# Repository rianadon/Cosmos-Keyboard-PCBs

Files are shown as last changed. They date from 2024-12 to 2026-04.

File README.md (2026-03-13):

# Cosmos Keyboard PCBs

This repository contains the sources and specs for the PCBs I've made for my pet project, [Cosmos Keyboard Generator](https://ryanis.cool/cosmos).

## Plum Twist

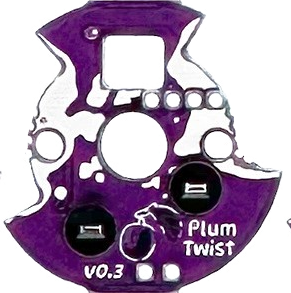
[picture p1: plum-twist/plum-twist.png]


A single-key PCB, with hotswap and RGB support that locks into place. [[Main Website](https://ryanis.cool/cosmos/plum-twist/)] [[Buy](https://cosmos-store.ryanis.cool/products/plum-twist)]

It's similar in functionality to the [Amoeba PCBs](https://github.com/JKing-B16/keyboard-pcbs) (in fact I've used some of the same footprints), but I've switched to large SMD pads to make wiring easier and designed the footprint to twist into a custom socket.

The version here on GitHub is pared down in terms of artwork and panelization, as my goal here is to make it easy for you to produce your own functionally identical version, not copy 1:1 what I sell. It's cheaper through JLC to buy the non-panelized version anyways. See the [subfolder's README](./plum-twist/README.md) for instructions on manufacturing these yourself.

Pinouts and wiring instructions are [on the Plum Twist website](https://ryanis.cool/cosmos/plum-twist/wiring). *A choc version is sadly impossible because the choc hotswap socket is too large to enable twisting while keeping the PCB footprint small.*

## Lemon Microcontroller

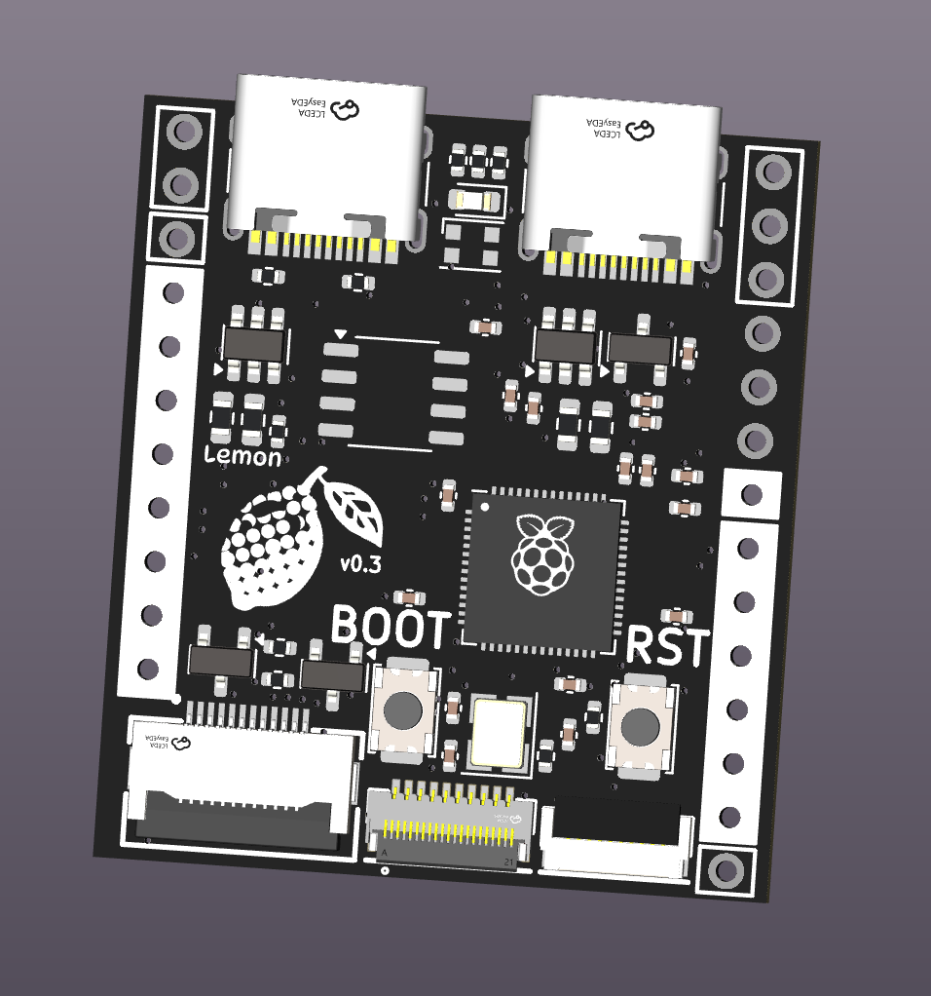
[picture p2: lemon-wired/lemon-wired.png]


An RP2040-based microcontroller with 2 spec-compliant USB ports, a VIK connector, and FPC connectors for connecting keys. [[Main Website](https://ryanis.cool/cosmos/lemon/)] [[Buy](https://cosmos-store.ryanis.cool/collections/lemon)]

The rightmost USB (closest to the RP2040 chip) is for programming. The leftmost PCB (by the SPI flash) cannot be used for programming. See the [subfolder's README](./lemon-wired/README.md) for pinouts, QMK examples, and more.

## Lemon Wireless Microcontroller

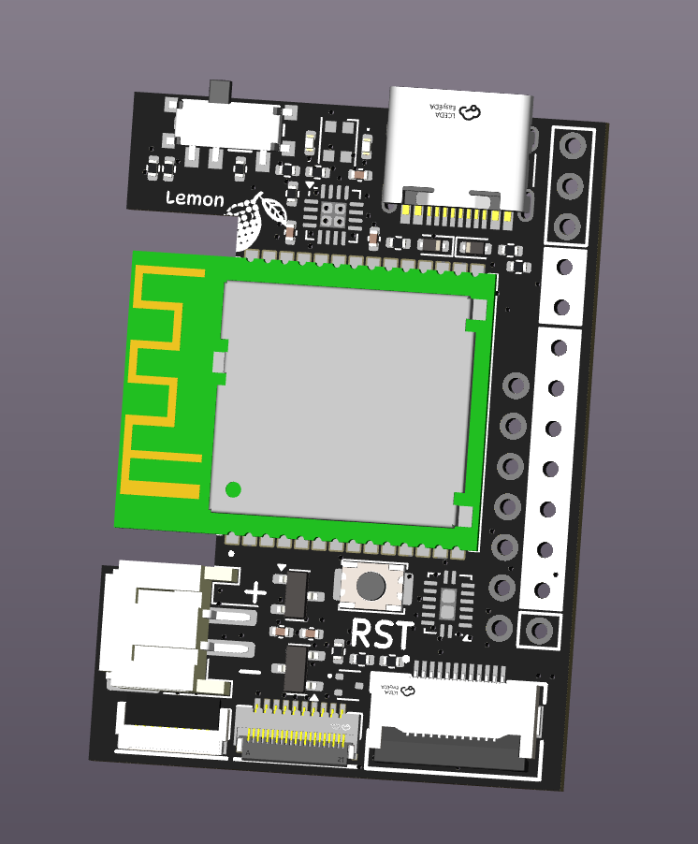
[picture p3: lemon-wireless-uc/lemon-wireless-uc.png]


An NRF52840-based microcontroller with a USB port, battery connector & charger, on/off switch, a VIK connector, and FPC connectors for connecting keys. [[Main Website](https://ryanis.cool/cosmos/lemon/)] [[Buy](https://cosmos-store.ryanis.cool/collections/lemon)]

Because it uses a shift register to drive columns, this board is capable of driving large keyboards even with external modules and lighting. See the [subfolder's README](./lemon-wireless-uc/README.md) for more information.

## Cactus Connector

A splitter for VIK cables. [[Docs](https://ryanis.cool/cosmos/docs/pcbs/cactus-connector)] [[Buy](https://cosmos-store.ryanis.cool/products/cactus-connector-for-vik)]

## Licensing

I license the subprojects differently, so refer to each subdirectory for licensing information.

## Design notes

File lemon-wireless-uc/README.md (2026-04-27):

# Lemon Wireless Microcontroller

[Documentation is on the Cosmos Docs.](https://ryanis.cool/cosmos/docs/pcbs/lemon-wireless/)

## Pinouts

### V0.2 Pinout

[Click for pinout picture](./lemon-pcb-wireless-pinout-v02.png)

### V0.3 Pinout

[Click for pinout picture](./lemon-pcb-wireless-pinout-v03.png)

### V0.4 Pinout

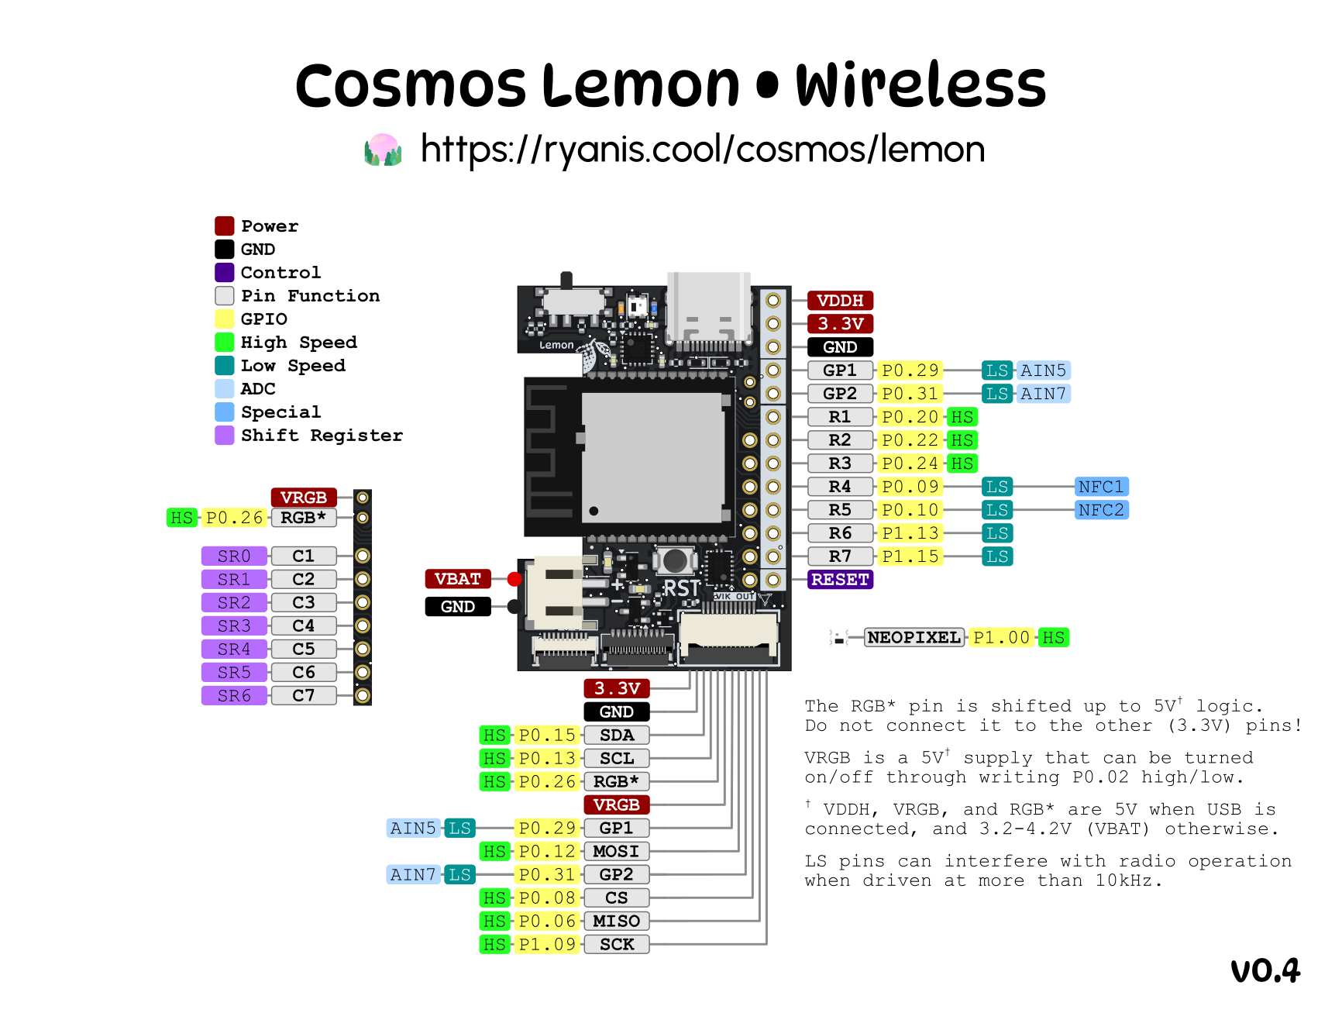
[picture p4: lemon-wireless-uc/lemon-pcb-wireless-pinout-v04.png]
Pinout picture


## VIK Information

| Category | Classification | Response |
| ---  | --- | --- |
| FPC connector | Required | :heavy_check_mark: |
| Breakout pins | Recommended | :heavy_check_mark: |
| Supplies: SPI | Required | :heavy_check_mark: |
| Supplies: I2C | Required | :heavy_check_mark: |
| I2C on main PCB | Discouraged | no |
| I2C pull ups | Informative | N/A |
| Supplies: RGB | Required | :heavy_check_mark: |
| Supplies: Extra GPIO 1 | Required | Analog/Digital |
| Supplies: Extra GPIO 2 | Required | Analog/Digital |

GPIO and SPI & I2C should be fully VIK-compatible. RGB can be used on one of the flex PCB connector, through-hole pad, or VIK module, but not multiple at the same time. This is a limitation of the flex PCB not having an RGB return pin. If you are using RGB through the VIK connector, solder the "RGB->VIK" jumper.

When connected to USB, 5V on the VIK connector will be 5V. However, it will be equal to battery voltage when operating off battery power (3.3-4.2V).

## License

Cosmos Keyboards invests time and resources providing this open source design, please support Cosmos and open-source hardware by purchasing products from Cosmos!

Designed by Ryan Adolf/rianadon for Cosmos Keyboards.

Creative Commons Attribution/Share-Alike, all text above must be included in any redistribution. See license.txt for additional details.

*adapted from Adafruit's Creative Commons Attribution/Share-Alike license.*

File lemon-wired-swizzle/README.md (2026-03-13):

# Lemon Wired Swizzle Microcontroller

This is a version of the Lemon Wired that swap the two USB ports depending on which one has power incoming.

The pinout is equivalent to v0.4 of the Lemon Wired. However, while GP16 was previously now unused, it's now the software override for the USB swap.

## Theory of operation

I use LM6620 to isolate the the VBUS voltages on both USB sockets. This part has an ST pin that indicates which VBUS was powered. This ST pin drives sel, and if sel is not overwrittten by GP16, then the two USB data lines are swapped using FSUSB42MUX.

Shortly after the device is powered on, power is applied to both VBUS using a PMOS with an RC circuit at the gate to ensure there is a delay so that ST can settle before both VBUS are turned on. Because of the hysteresis on LM6620, turning on both VBUS does not change the ST pin.

## License

Cosmos Keyboards invests time and resources providing this open source design, please support Cosmos and open-source hardware by purchasing products from Cosmos!

Designed by Ryan Adolf/rianadon for Cosmos Keyboards.

Creative Commons Attribution/Share-Alike, all text above must be included in any redistribution. See license.txt for additional details.

*adapted from Adafruit's Creative Commons Attribution/Share-Alike license.*

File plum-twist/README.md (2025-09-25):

# Plum Twist

Pinouts and wiring instructions: [see the Plum Twist website](https://ryanis.cool/cosmos/plum-twist/wiring).

## Manufacturing

To maintain compatibility with the [sockets in Cosmos](https://github.com/rianadon/Cosmos-Keyboards/blob/main/src/assets/key-mx-pcb-plum.step), make sure you manufacture these with 1.2mm thickness.

To assemble these yourself these you'll need 1x of these for every PCB:

- 1N4148 Diodes in SOD-323 Package
- Kailh MX Hotswap Sockets (CPG151101S11)
- SK6812MINI-E LEDs (optional and frankly not worth the time)

The hotswap sockets are the most expensive of the three and AliExpress tends to have the best prices for them. LCSC also has good prices on the purple hotswap sockets. YMMV.

## Assembly

Diode orientation doesn't matter as long as you're consistent. If you want to match the ones I sell, the cathode (the white line on the diode) should face inwards close to the big hole in the center of the PCB. This is also how the diode is oriented in the KiCAD file.

The rest of the placements is explained by the [wiring guide](https://ryanis.cool/cosmos/plum-twist/wiring). Set the hotswap socket in so that it's not blocking the center hole, and the RGB LED should be placed with the chopped corner (GND) closest to the center hole.

## License

All hardware designs, excluding images and logos, are licensed under CERN-OHL-P-2.0 (permissive variant of the CERN Open Hardware License, see LICENSE.txt).

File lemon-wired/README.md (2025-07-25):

# Lemon Microcontroller

[Documentation is on the Cosmos Docs.](https://ryanis.cool/cosmos/docs/pcbs/lemon-wired/)

## Pinouts

### V0.0 Pinouts
```
Secondary USB pins: GP0 (D+) and GP1 (D-)
Column pins: GP11, GP24, GP23, GP22, GP21, GP20, GP7
Row pins: GP10, GP6, GP9, GP4, GP8, GP5, GP3
LED pin: GP25
VIK SPI: GP12 (RX), GP13 (CS), GP13 (SCK), GP15 (TX). Uses SPI1.
VIK I2C: GP18 (SDA0, GP19 (SCL). Uses I2C 1.
Onboard neopixel: GP17
```

**Notes for v0.0**: Due to an error in routing, GP25 and GP11 got are in the wrong spot in the FPC connector (FPC1) to be compatible with the Skree PCBs. This is why they are swapped in the pinout and don't match the schematic. The reset button didn't get wired in the PCB, so to upload you need to hold down BOOT while plugging in the microcontroller.

### V0.2 Pinouts

```
Secondary USB pins: GP0 (D+) and GP1 (D-)
Column pins: GP25, GP24, GP23, GP22, GP21, GP20, GP7
Row pins: GP10, GP6, GP9, GP4, GP8, GP5, GP3
LED data pin: GP2
LED power pin: GP11 (active low)
VIK SPI: GP12 (RX), GP13 (CS), GP13 (SCK), GP15 (TX). Uses SPI1.
VIK I2C: GP18 (SDA0, GP19 (SCL). Uses I2C 1.
VIK GPIO: GP16 (1st, digital only), GP26 (2nd, has ADC)
Onboard neopixel: GP17
```

### V0.3 Pinouts

[Click for pinout image](./lemon-pcb-pinout-v03.png)

```
Secondary USB pins: GP0 (D+) and GP1 (D-)
Column pins: GP25, GP24, GP23, GP22, GP21, GP20, GP7
Row pins: GP10, GP6, GP9, GP4, GP8, GP5, GP3
LED data pin: GP2
LED power pin: GP11 (active low)
VIK SPI: GP12 (RX), GP13 (CS), GP13 (SCK), GP15 (TX). Uses SPI1.
VIK I2C: GP18 (SDA0, GP19 (SCL). Uses I2C 1.
VIK GPIO: GP26, GP27 (both have ADC)
Onboard neopixel: GP17
```

In V0.3, the LED data pin (5V logic) is broken out as a pad in place of GP2 (3.3V logic).

### V0.4 Pinouts

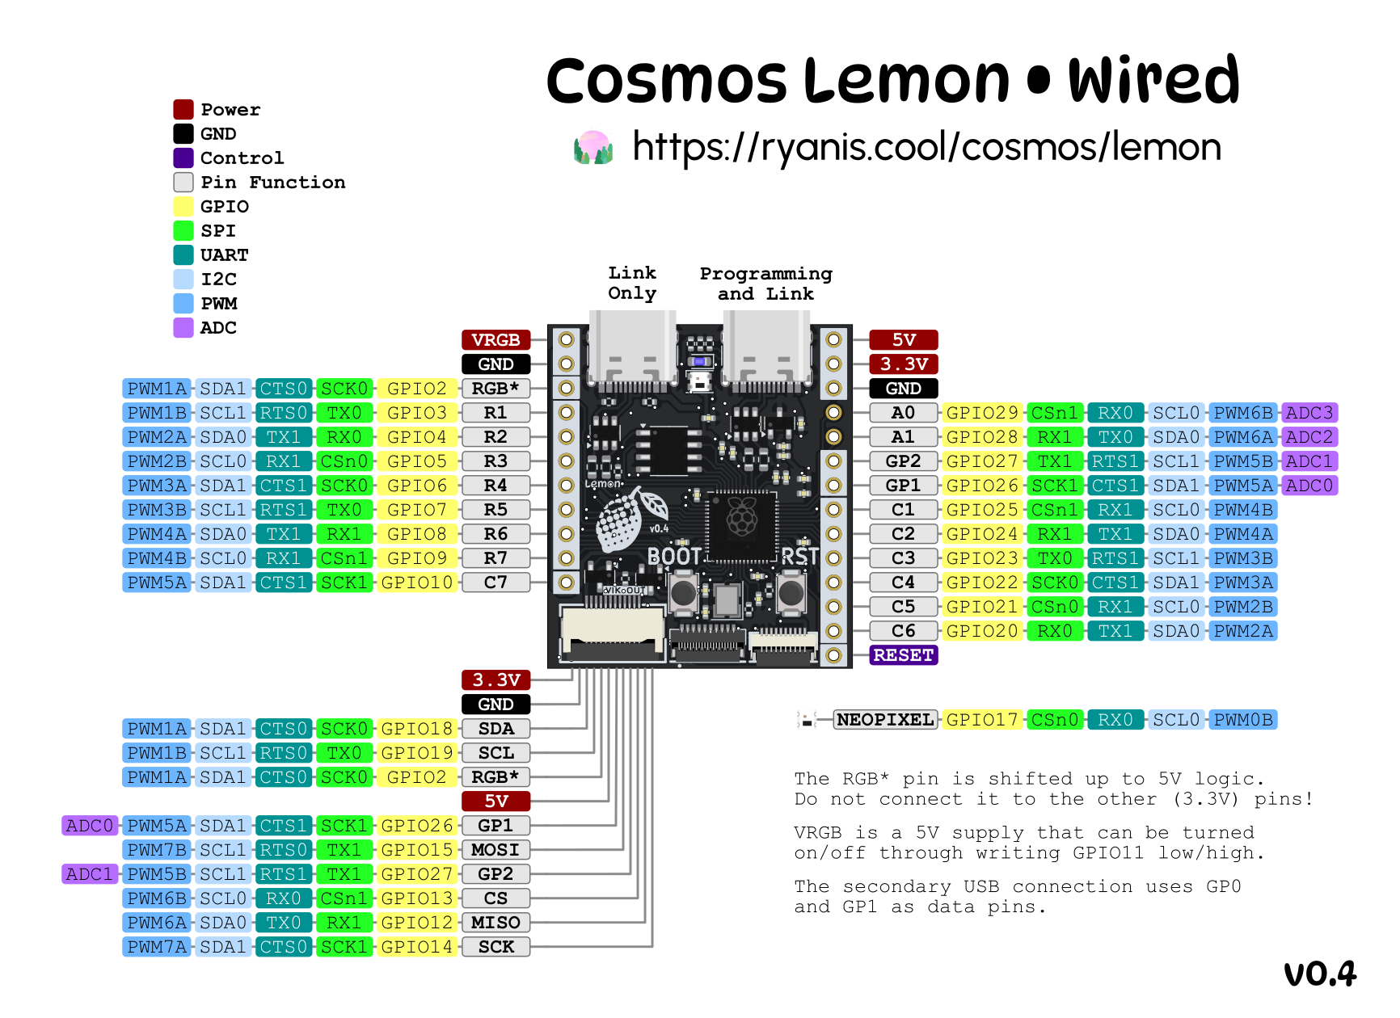
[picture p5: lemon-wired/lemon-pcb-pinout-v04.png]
Pinout image


```
Secondary USB pins: GP0 (D+) and GP1 (D-)
Column pins: GP25, GP24, GP23, GP22, GP21, GP20, GP10
Row pins: GP3, GP4, GP5, GP6, GP7, GP8, GP9
LED data pin: GP2
LED power pin: GP11 (active low)
VIK SPI: GP12 (RX), GP13 (CS), GP13 (SCK), GP15 (TX). Uses SPI1.
VIK I2C: GP18 (SDA0, GP19 (SCL). Uses I2C 1.
VIK GPIO: GP26, GP27 (both have ADC)
Onboard neopixel: GP17
```

I rearranged the row/column pin order in this one to help with handwiring.

## VIK Information

| Category | Classification | Response |
| ---  | --- | --- |
| FPC connector | Required | :heavy_check_mark: |
| Breakout pins | Recommended | :heavy_check_mark: |
| Supplies: SPI | Required | :heavy_check_mark: |
| Supplies: I2C | Required | :heavy_check_mark: |
| I2C on main PCB | Discouraged | no |
| I2C pull ups | Informative | N/A |
| Supplies: RGB | Required | :heavy_check_mark: |
| Supplies: Extra GPIO 1 | Required | Analog/Digital |
| Supplies: Extra GPIO 2 | Required | Analog/Digital |

Voltage, SPI & I2C should be fully VIK-compatible. RGB can be used on one of the flex PCB connector, through-hole pad, or VIK module, but not multiple at the same time. This is a limitation of the flex PCB not having an RGB return pin. If you are using RGB through the VIK connector, solder the "RGB->VIK" jumper.

## Testing USB & LED

If you want to have some fun, install Arduino and then from Arduino IDE install the Adafruit TinyUSB and Adafruit NeoPixel libraries. Set your board to `Generic RP2040`, set `Tools -> CPU Speed` to `120 MHz`, and upload the `lemon_test` sketch in this repository. With the serial monitor open, you should see information printed when you plug in/out devices to the secondary USB port. The RGB LED will also slowly fade through colors.

Alternatively, you can upload `File -> Examples -> Adafruit TinyUSB Library -> DualRole -> Simple -> device_info`, which will only test USB. I based `lemon_test` off of this code.

## QMK examples

This is out of date. Refer to the documentation on the Cosmos site for the latest on firmware.

~~I've uploaded a simple QMK example with the correct wiring for the microcontroller. It uses the full 7x7 matrix, so it's great for testing that everything works. I haven't gotten to making the split work correctly though. For that you need to reference https://github.com/sekigon-gonnoc/qmk_firmware/tree/rp2040/keyboards/pico_pico_usb.~~

~~To use it copy `lemon-microcontroller/lemon7x7-qmk-v0` to `<qmk_firmware>/keyboards/cosmos/lemon7x7` then run `qmk flash -j4 -kb cosmos/lemon7x7 -km via -bl uf2-split-right`.~~

~~If you received your Lemon from me, it's probably already running this program.~~

## License

Cosmos Keyboards invests time and resources providing this open source design, please support Cosmos and open-source hardware by purchasing products from Cosmos!

Designed by Ryan Adolf/rianadon for Cosmos Keyboards.

Creative Commons Attribution/Share-Alike, all text above must be included in any redistribution. See license.txt for additional details.

*adapted from Adafruit's Creative Commons Attribution/Share-Alike license.*

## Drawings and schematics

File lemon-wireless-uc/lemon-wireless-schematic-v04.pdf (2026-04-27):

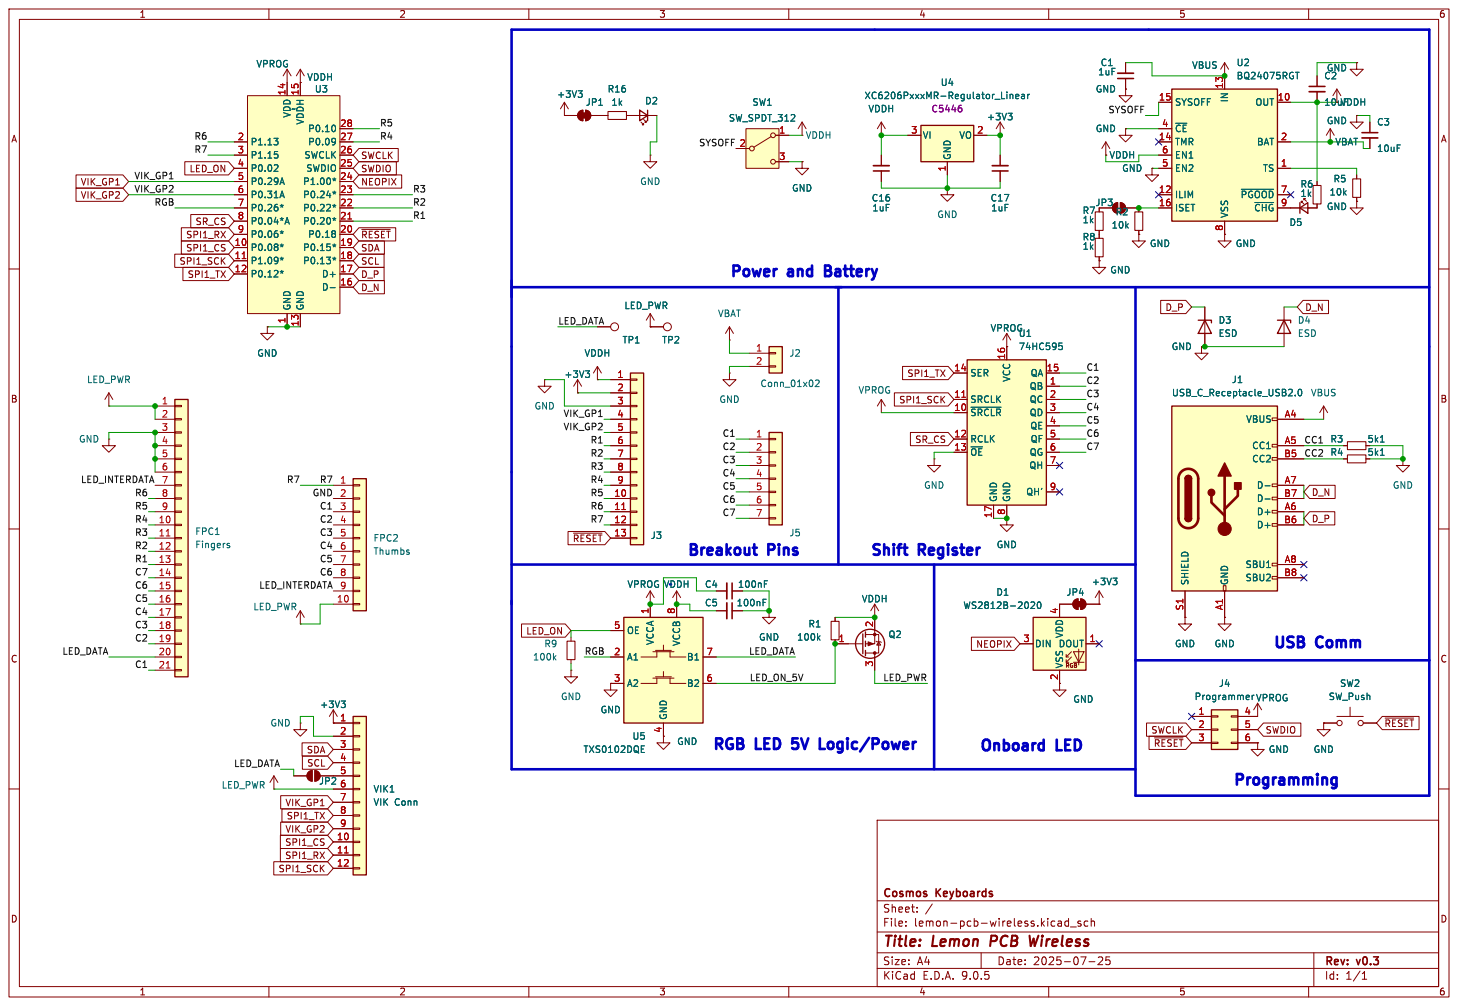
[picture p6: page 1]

8 OUT 10 BAT 2 TS 1 ~{PGOOD}7 ~{CHG}9 VBUS D5 R2

8 OUT 10 BAT 2 TS 1 ~{PGOOD}7 ~{CHG}9 U2BQ24075RGT VPROG

1 VDDH 15 GND 13 P0.10 28 P0.09 27 SWCLK 26 SWDIO 25 P1.00* 24 P0.24* 23 P0.22* 22 P0.20* 21 P0.18 20 P0.15* 19 P0.13* 18 D+ 17 D- 16 U3 ~ R5

1 VDDH 15 GND 13 P0.10 28 P0.09 27 SWCLK 26 SWDIO 25 P1.00* 24 P0.24* 23 P0.22* 22 P0.20* 21 P0.18 20 P0.15* 19 P0.13* 18 D+ 17 D- 16 +3V3

8 QA 15 QB 1 QC 2 QD 3 QE 4 QF 5 QG 6 QH 7 QH' 9 GND GND

Id: 1/1 Title: Lemon PCB Wireless

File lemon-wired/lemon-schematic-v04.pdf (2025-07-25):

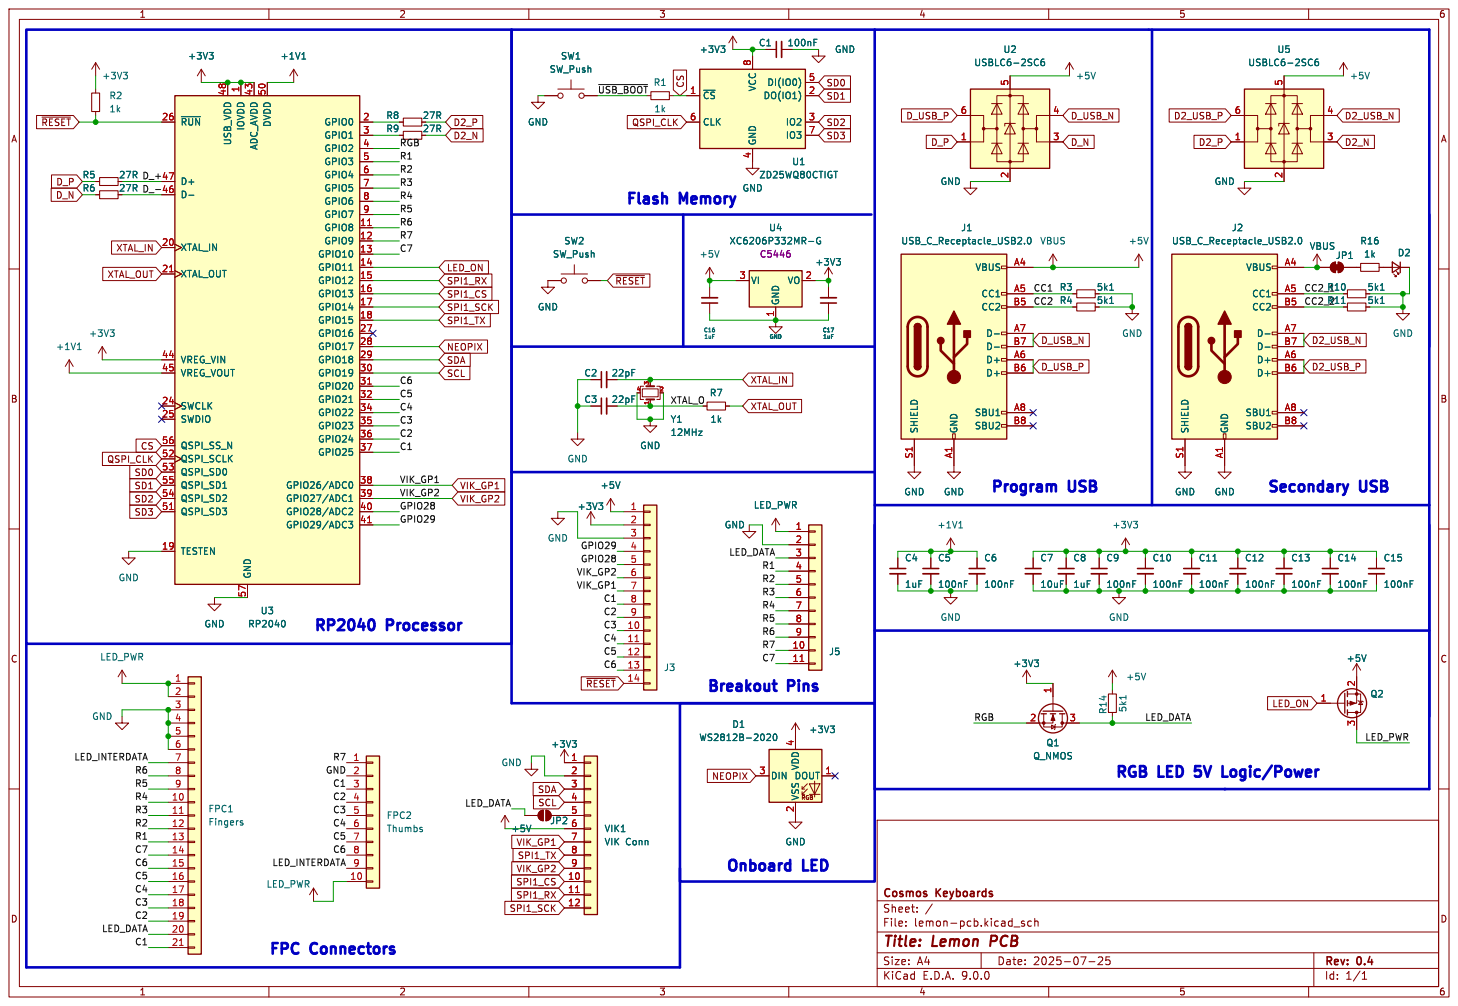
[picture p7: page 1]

RGB LED 5V Logic/Power

Id: 1/1 Title: Lemon PCB

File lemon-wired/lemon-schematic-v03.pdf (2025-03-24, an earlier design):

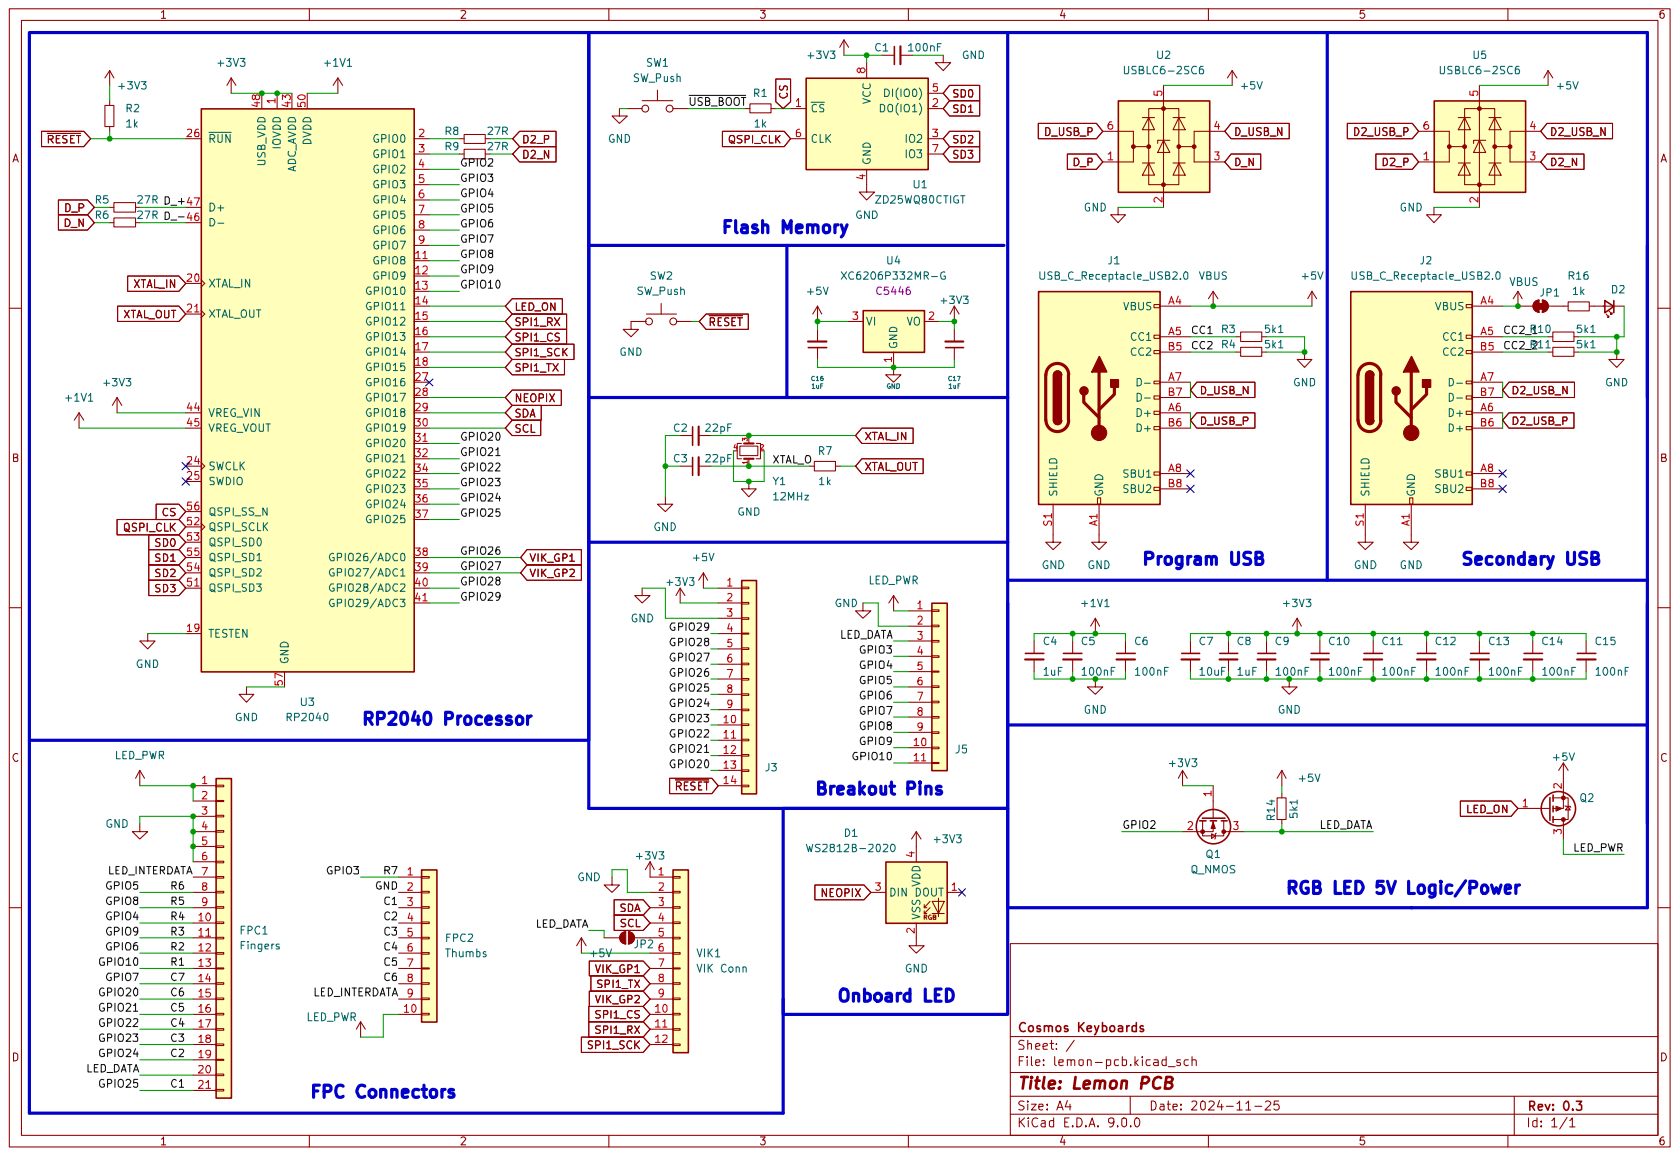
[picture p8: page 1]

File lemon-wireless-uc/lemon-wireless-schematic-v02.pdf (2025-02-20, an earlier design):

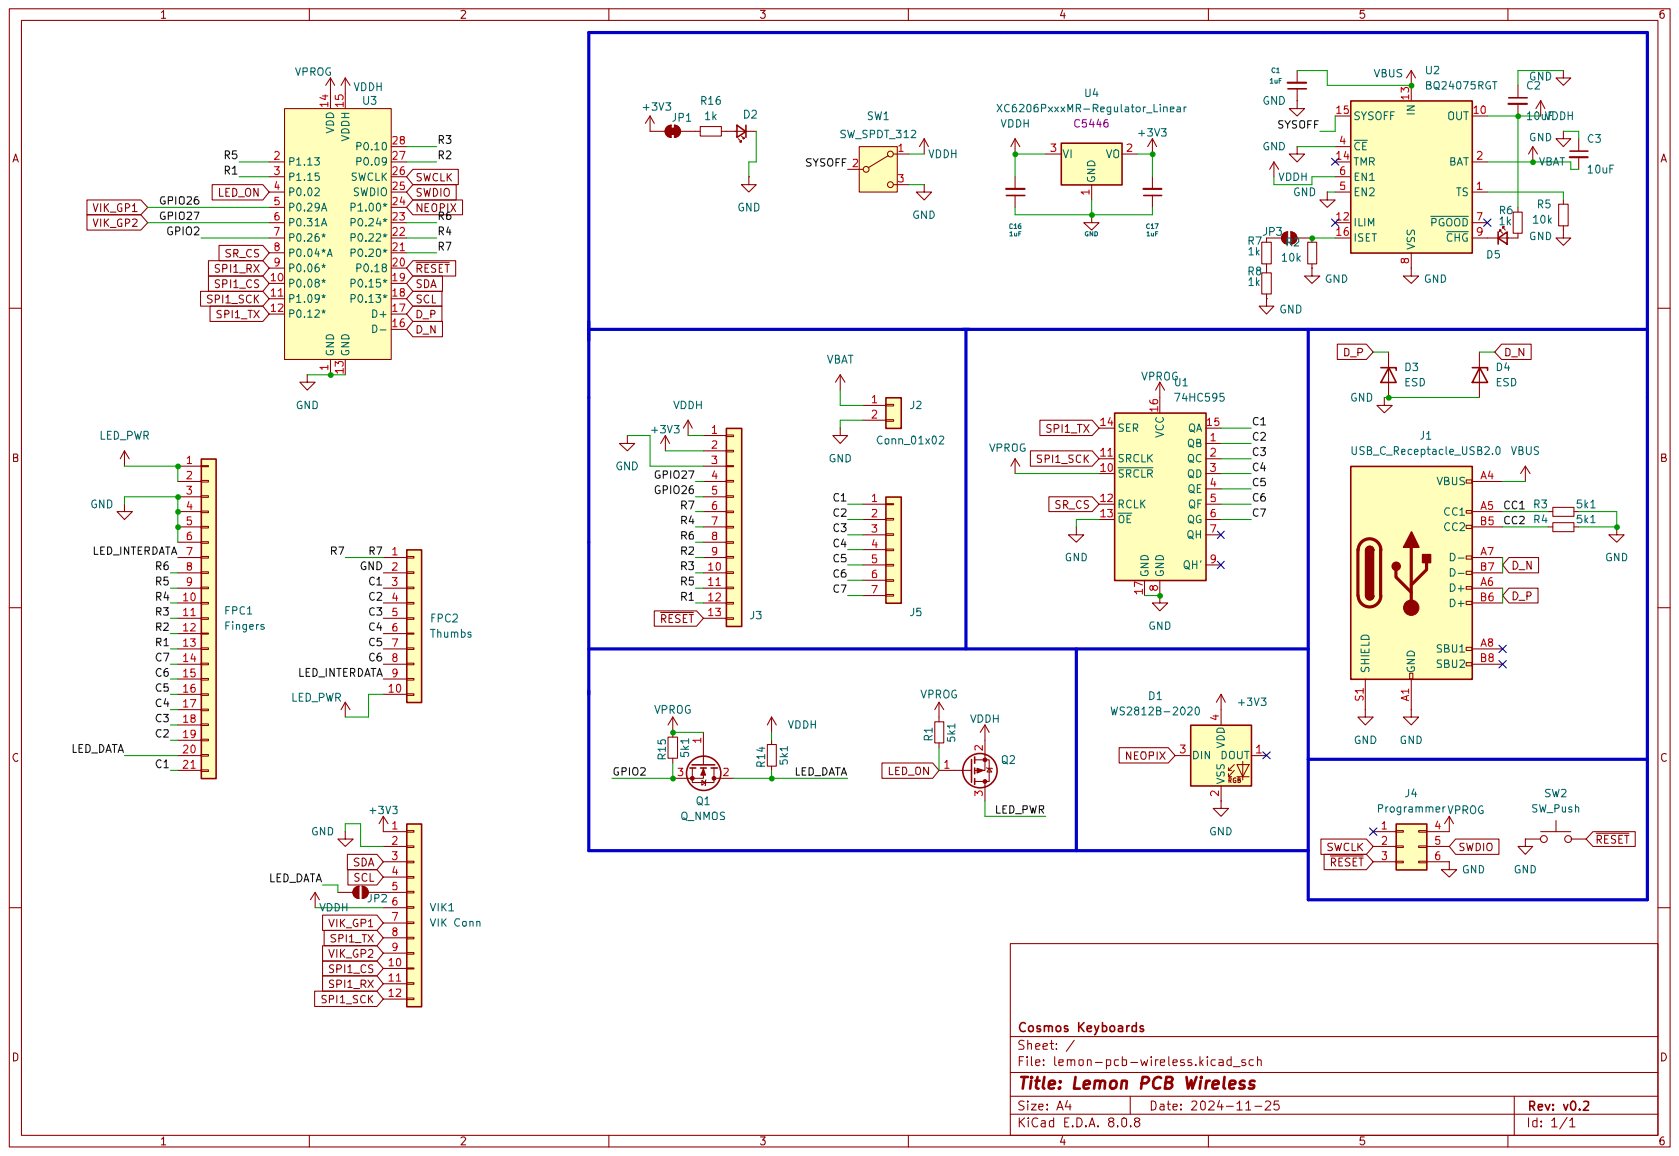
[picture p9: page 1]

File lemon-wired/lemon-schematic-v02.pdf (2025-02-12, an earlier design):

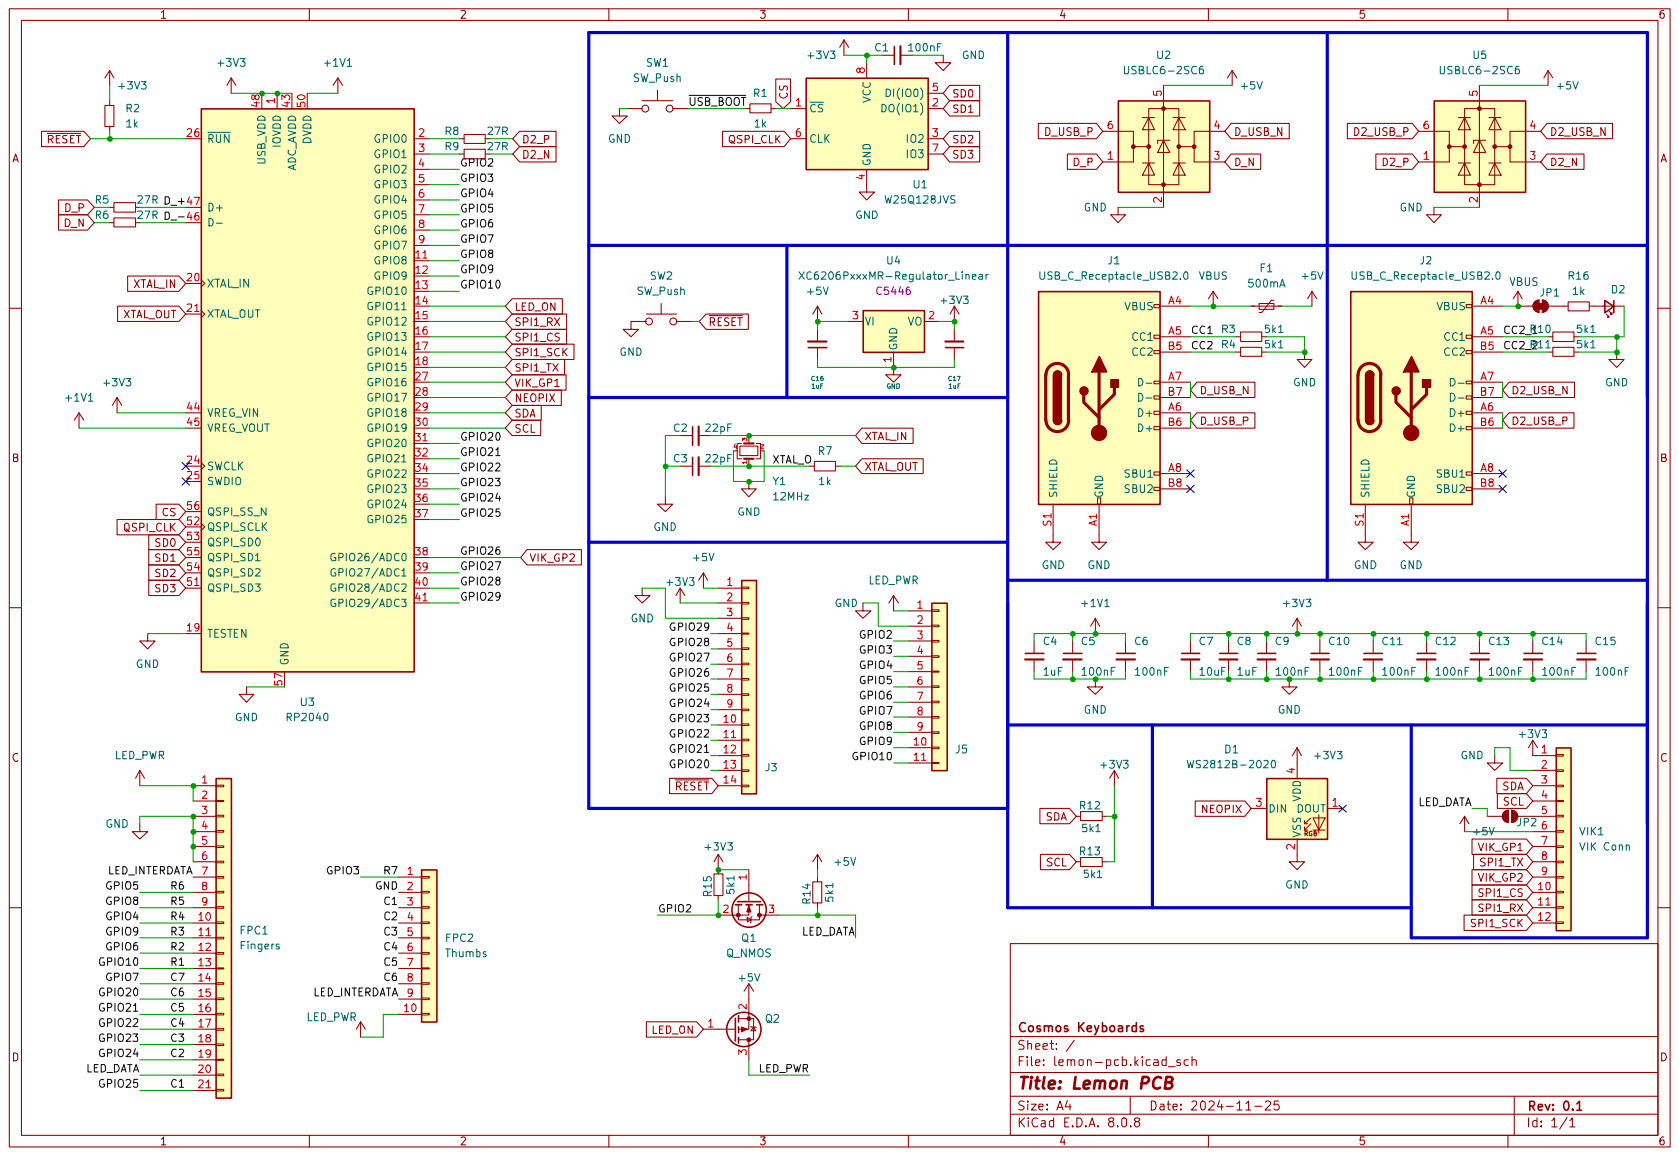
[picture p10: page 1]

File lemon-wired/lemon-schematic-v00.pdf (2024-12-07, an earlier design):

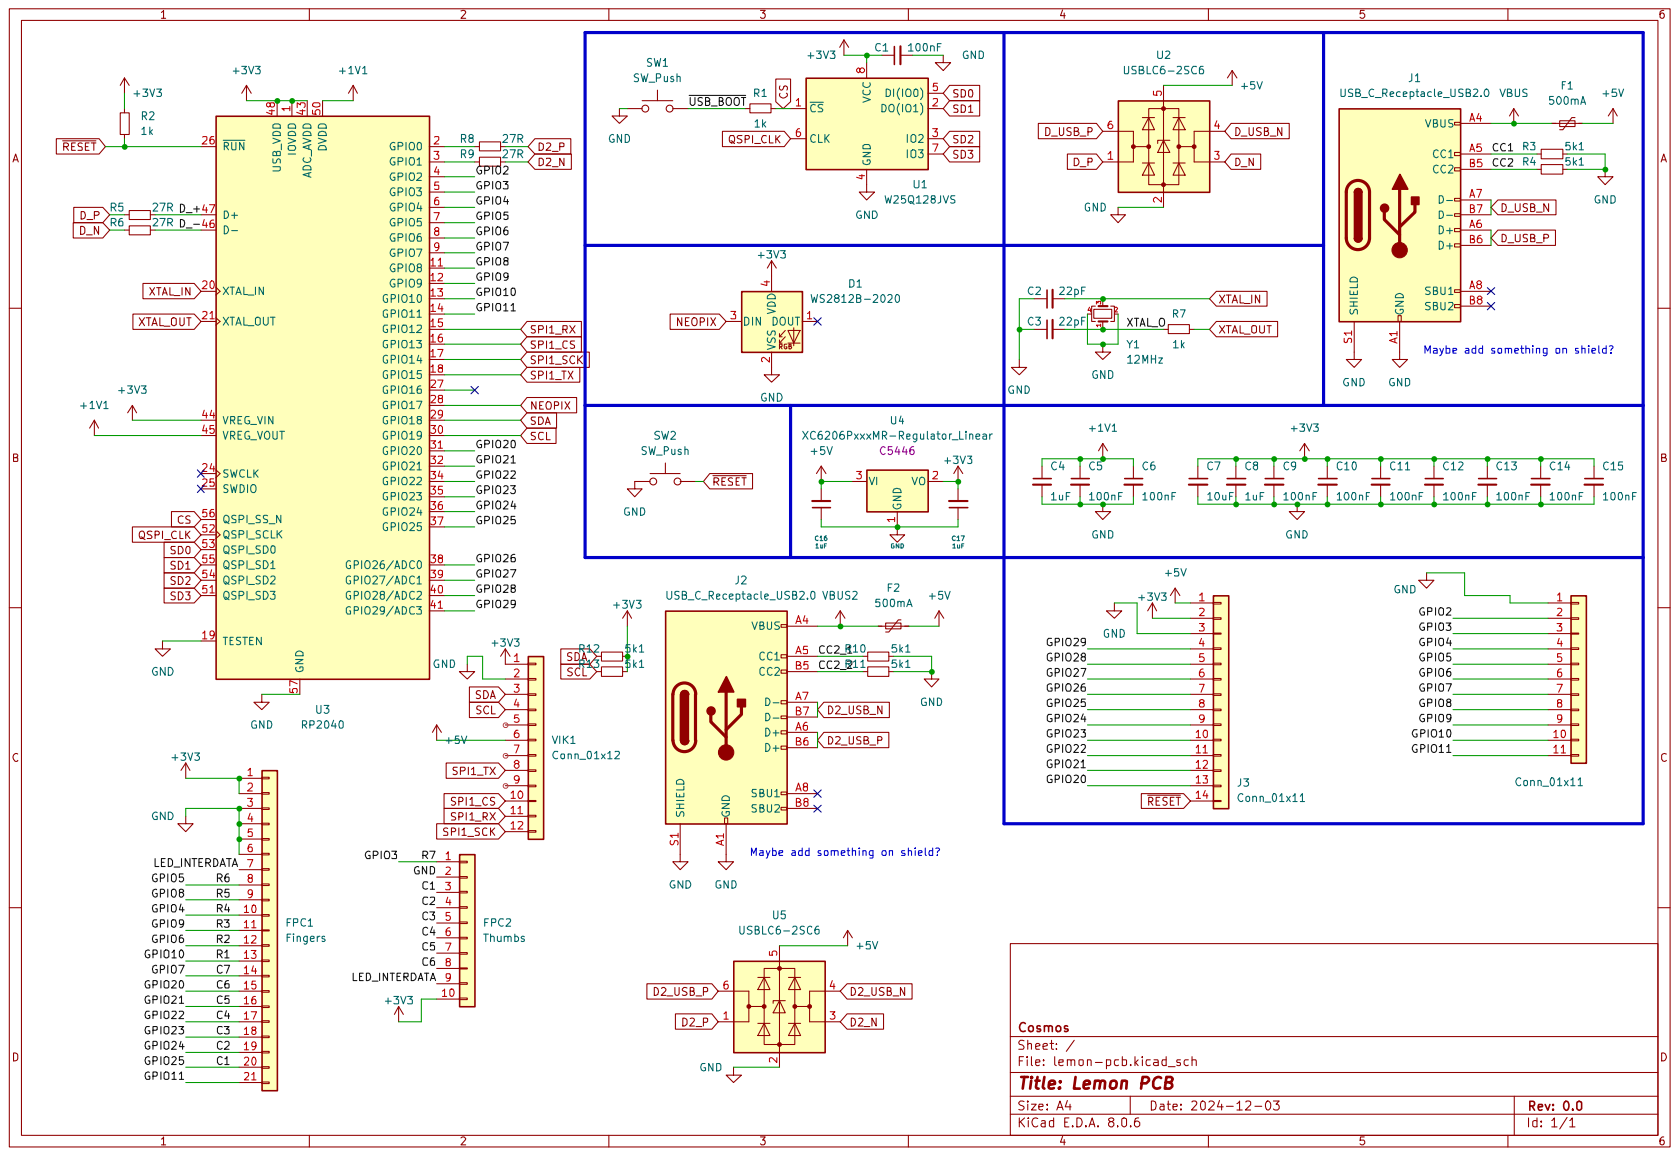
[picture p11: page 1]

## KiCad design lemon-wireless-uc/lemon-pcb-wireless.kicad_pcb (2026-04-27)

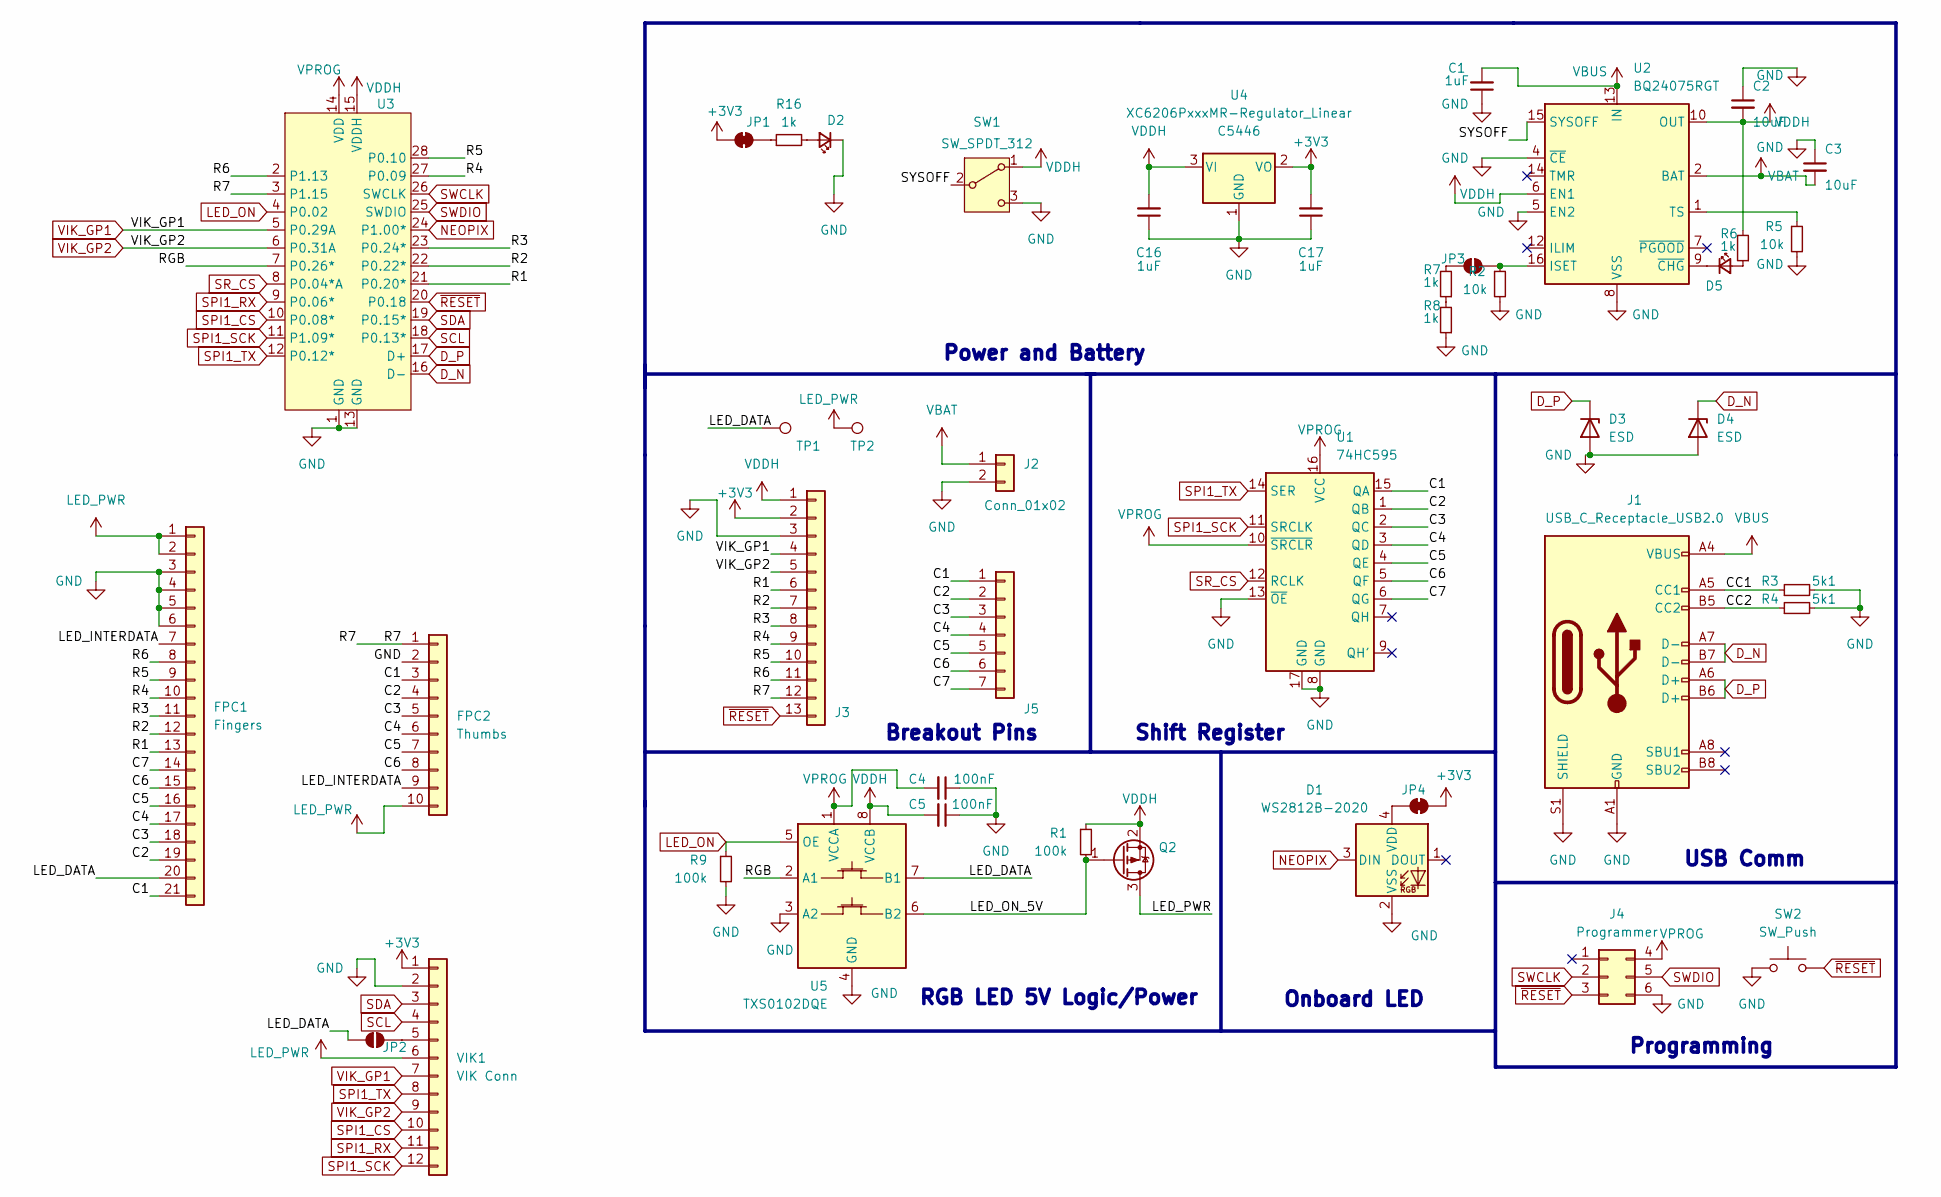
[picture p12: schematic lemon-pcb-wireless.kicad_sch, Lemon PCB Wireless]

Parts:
C1: 1uF; C_0402_1005Metric; LCSC C52923
C2, C3: 10uF; C_0402_1005Metric; LCSC C15525
C4, C5: 100nF; C_0402_1005Metric; LCSC C1525
C16, C17: 1uF; C_0603_1608Metric; LCSC C15849
D1: WS2812B-2020; LED_WS2812B-2020_PLCC4_2.0x2.0mm; LCSC C965555
D2: LED_Small; LED_0402_1005Metric; LCSC C7496802
D3, D4: ESD; D_SOD-523; LCSC C18723415
D5: LED_Small; LED_0402_1005Metric; LCSC C779448
FPC1: Fingers; FPC-SMD_21P-P0.30_HDGC_0.3K-QX-21PWB; LCSC C3012330
FPC2: Thumbs; FPC-SMD_10P-P0.50_HC-FPC-05-09-10RLTAG; LCSC C5213731
J1: USB_C_Receptacle_USB2.0; USB_C_Receptacle_HRO_TYPE-C-31-M-12; LCSC C165948
J2: Conn_01x02; JST_PH_S2B-PH-SM4-TB_1x02-1MP_P2.00mm_Horizontal; LCSC C295747
J3: Conn_01x11; PinHeader_1x13_P2.54mm_Vertical
J4: Programmer; j2thing
J5: Conn_01x11; PinHeader_1x07_P2.54mm_Vertical
JP1, JP4: SolderJumper_2_Bridged; SolderJumper-2_P1.3mm_Bridged_Pad1.0x1.5mm
JP2, JP3: SolderJumper_2_Open; SolderJumper-2_P1.3mm_Open_Pad1.0x1.5mm
Q2: Q_PMOS_SGD; SOT-23; LCSC C15127
R1, R9: 100k; R_0402_1005Metric; LCSC C25741
R2, R5: 10k; R_0402_1005Metric; LCSC C25744
R3, R4: 5k1; R_0402_1005Metric; LCSC C25905
R6, R7, R8, R16: 1k; R_0402_1005Metric; LCSC C11702
SW1: SW_SPDT_312; MK-12C02-G020_GSW; LCSC C963206
SW2: SW_Push; SW_Push_SPST_NO_Alps_SKRK; LCSC C115357
TP1, TP2: TestPoint; TestPoint_THTPad_D1.0mm_Drill0.5mm
U1: 74HC595; DHVQFN-16-1EP_2.5x3.5mm_P0.5mm_EP1x2mm; LCSC C730243
U2: BQ24075RGT; VQFN-16-1EP_3x3mm_P0.5mm_EP1.6x1.6mm; LCSC C15464
U3: XCVR_MS88SF2
U4: XC6206PxxxMR-Regulator_Linear; SOT-23; LCSC C5446
U5: TXS0102DQE; X2SON-8_1.4x1mm_P0.35mm
VIK1: VIK Conn; FPC-SMD_FPC05012-09200; LCSC C19273928

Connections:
+3V3: C17.2, J3.2, JP1.2 (B), JP4.2 (B), U4.2 (VO), VIK1.1
/C1: FPC1.21, FPC2.3, J5.1, U1.15 (QA)
/C2: FPC1.19, FPC2.4, J5.2, U1.1 (QB)
/C3: FPC1.18, FPC2.5, J5.3, U1.2 (QC)
/C4: FPC1.17, FPC2.6, J5.4, U1.3 (QD)
/C5: FPC1.16, FPC2.7, J5.5, U1.4 (QE)
/C6: FPC1.15, FPC2.8, J5.6, U1.5 (QF)
/C7: FPC1.14, J5.7, U1.6 (QG)
/CC1: J1.A5 (CC1), R3.1
/CC2: J1.B5 (CC2), R4.1
/LED_DATA: FPC1.20, JP2.1 (A), TP1.1, U5.7 (B1)
/LED_INTERDATA: FPC1.7, FPC2.9
/LED_ON_5V: Q2.1 (G), R1.2, U5.6 (B2)
/R1: FPC1.13, J3.6, U3.21 (P0.20*)
/R2: FPC1.12, J3.7, U3.22 (P0.22*)
/R3: FPC1.11, J3.8, U3.23 (P0.24*)
/R4: FPC1.10, J3.9, U3.27 (P0.09)
/R5: FPC1.9, J3.10, U3.28 (P0.10)
/R6: FPC1.8, J3.11, U3.2 (P1.13)
/R7: FPC2.1, J3.12, U3.3 (P1.15)
/RGB: U3.7 (P0.26*), U5.2 (A1)
/SYSOFF: SW1.2 (B), U2.15 (SYSOFF)
D_N: D4.1 (K), J1.A7 (D-), J1.B7 (D-), U3.16 (D-)
D_P: D3.1 (K), J1.A6 (D+), J1.B6 (D+), U3.17 (D+)
GND: C1.1, C2.1, C3.1, C4.1, C5.1, C16.1, C17.1, D1.2 (VSS), D2.1 (K), D3.2 (A), D4.2 (A), FPC1.3, FPC1.4, FPC1.5, FPC1.6, FPC2.2, J1.A1 (GND), J1.A12 (GND), J1.B1 (GND), J1.B12 (GND), J1.S1 (SHIELD), J2.2, J3.3, J4.6, R2.2, R3.2, R4.2, R5.2, R8.1, R9.2, SW1.3 (C), SW2.1, U1.8 (GND), U1.13 (~OE), U1.17 (GND), U2.4 (~CE), U2.5 (EN2), U2.8 (VSS), U2.17 (VSS), U3.1 (GND), U3.13 (GND), U4.1 (GND), U5.3 (A2), U5.4 (GND), VIK1.2
LED_ON: R9.1, U3.4 (P0.02), U5.5 (OE)
LED_PWR: FPC1.1, FPC1.2, FPC2.10, Q2.3 (D), TP2.1, VIK1.6
NEOPIX: D1.3 (DIN), U3.24 (P1.00*)
unnamed: D1.4 (VDD), JP4.1 (A)
unnamed: D2.2 (A), R16.2
unnamed: D5.2 (A), R6.1
unnamed: D5.1 (K), U2.9 (~CHG)
unnamed: JP1.1 (A), R16.1
unnamed: JP2.2 (B), VIK1.5
unnamed: JP3.1 (A), R2.1, U2.16 (ISET)
unnamed: JP3.2 (B), R7.2
unnamed: R7.1, R8.2
unnamed: R5.1, U2.1 (TS)
SCL: U3.18 (P0.13*), VIK1.4
SDA: U3.19 (P0.15*), VIK1.3
SPI1_CS: U3.10 (P0.08*), VIK1.10
SPI1_RX: U3.9 (P0.06*), VIK1.11
SPI1_SCK: U1.11 (SRCLK), U3.11 (P1.09*), VIK1.12
SPI1_TX: U1.14 (SER), U3.12 (P0.12*), VIK1.8
SR_CS: U1.12 (RCLK), U3.8 (P0.04*A)
SWCLK: J4.2, U3.26 (SWCLK)
SWDIO: J4.5, U3.25 (SWDIO)
VBAT: C3.2, J2.1, U2.2 (BAT), U2.3 (BAT)
VBUS: C1.2, J1.A4 (VBUS), J1.A9 (VBUS), J1.B4 (VBUS), J1.B9 (VBUS), U2.13 (IN)
VDDH: C2.2, C5.2, C16.2, J3.1, Q2.2 (S), R1.1, R6.2, SW1.1 (A), U2.6 (EN1), U2.10 (OUT), U2.11 (OUT), U3.15 (VDDH), U4.3 (VI), U5.8 (VCCB)
VIK_GP1: J3.4, U3.5 (P0.29A), VIK1.7
VIK_GP2: J3.5, U3.6 (P0.31A), VIK1.9
VPROG: C4.2, J4.4, U1.10 (~SRCLR), U1.16 (VCC), U3.14 (VDD), U5.1 (VCCA)
~RESET: J3.13, J4.3, SW2.2, U3.20 (P0.18)

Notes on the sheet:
RGB LED 5V Logic/Power
Breakout Pins
Programming
Shift Register
USB Comm
Power and Battery
Onboard LED

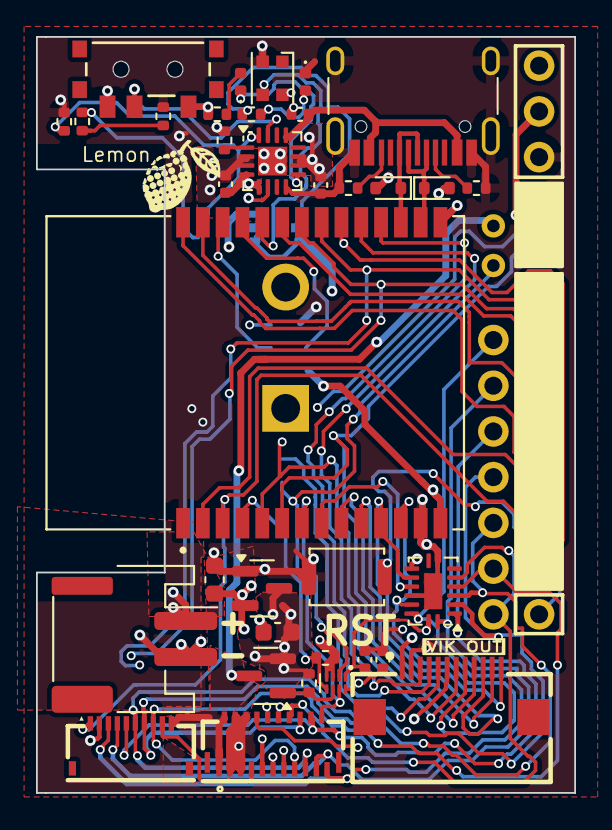
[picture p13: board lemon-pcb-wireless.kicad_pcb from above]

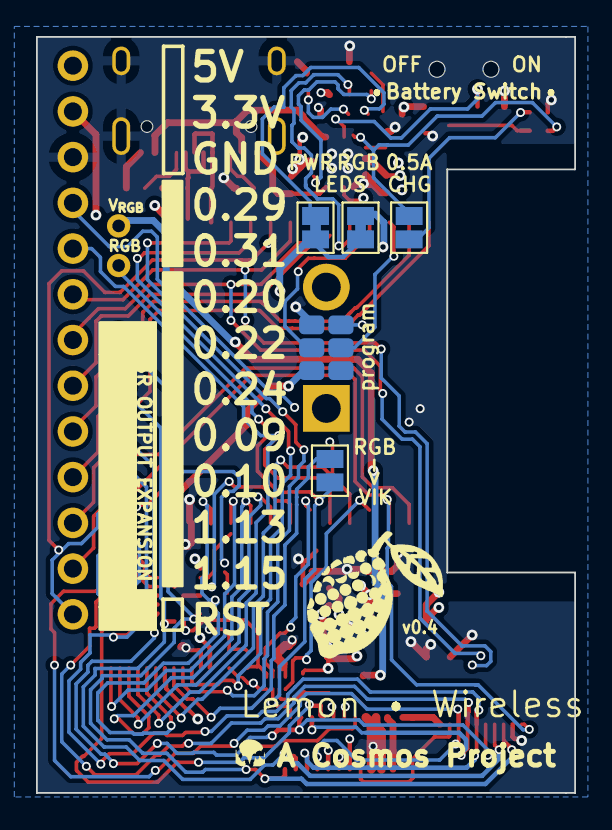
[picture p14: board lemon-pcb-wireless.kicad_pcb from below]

Board: 4 copper layers, 29.9 x 42.0 mm, 44 parts (7 on the bottom side), 54 nets.

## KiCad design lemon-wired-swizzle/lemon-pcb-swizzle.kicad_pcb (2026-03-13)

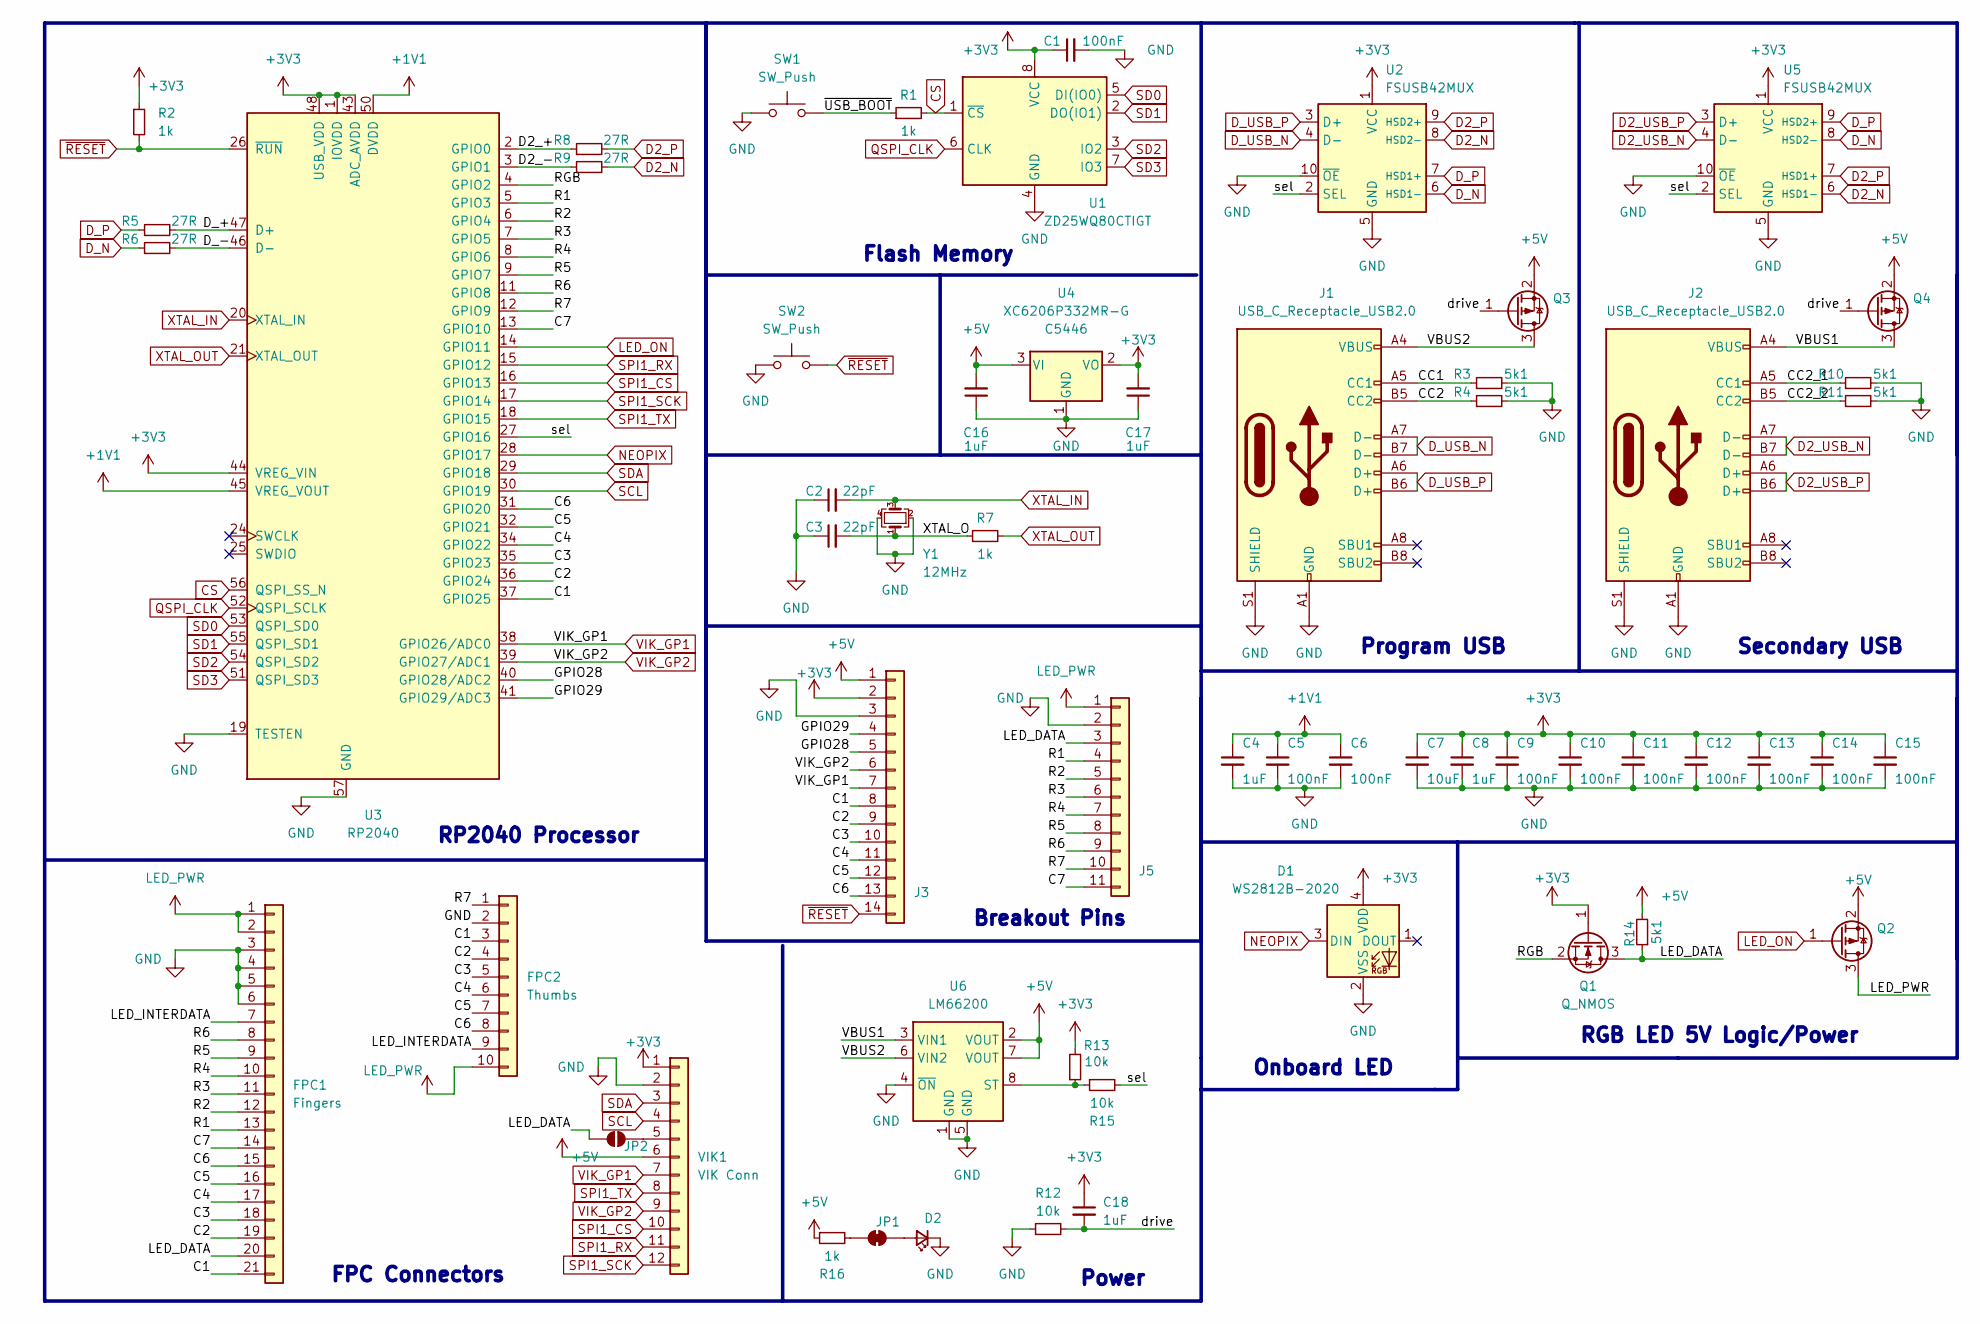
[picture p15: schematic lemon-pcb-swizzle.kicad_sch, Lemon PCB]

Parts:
C1, C5, C6, C9, C10, C11, C12, C13, C14, C15: 100nF; C_0402_1005Metric; LCSC C1525
C2, C3: 22pF; C_0402_1005Metric; LCSC C1555
C4, C8, C18: 1uF; C_0402_1005Metric; LCSC C52923
C7: 10uF; C_0402_1005Metric; LCSC C15525
C16, C17: 1uF; C_0603_1608Metric; LCSC C15849
D1: WS2812B-2020; LED_WS2812B-2020_PLCC4_2.0x2.0mm; LCSC C965555
D2: LED_Small; LED_0603_1608Metric; LCSC C7371898
FPC1: Fingers; LCSC C2919509
FPC2: Thumbs; LCSC C5213731
J1, J2: USB_C_Receptacle_USB2.0; USB_C_Receptacle_HRO_TYPE-C-31-M-12; LCSC C165948
J3: Conn_01x11; PinHeader_1x14_P2.54mm_Vertical
J5: Conn_01x11; PinHeader_1x11_P2.54mm_Vertical
JP1: SolderJumper_2_Bridged; SolderJumper-2_P1.3mm_Bridged_Pad1.0x1.5mm
JP2: SolderJumper_2_Open; SolderJumper-2_P1.3mm_Open_Pad1.0x1.5mm
Q1: Q_NMOS; SOT-23; LCSC C8545
Q2, Q3, Q4: Q_PMOS_SGD; SOT-23; LCSC C15127
R1, R2, R7, R16: 1k; R_0402_1005Metric; LCSC C11702
R3, R4, R10, R11, R14: 5k1; R_0402_1005Metric; LCSC C25905
R5, R6, R8, R9: 27R; R_0603_1608Metric; LCSC C25190
R12, R13, R15: 10k; R_0402_1005Metric; LCSC C25744
SW1, SW2: SW_Push; SW_Push_SPST_NO_Alps_SKRK; LCSC C115357
U1: ZD25WQ80CTIGT; SOP-8_3.9x4.9mm_P1.27mm; LCSC C7525143
U2, U5: FSUSB42MUX; MSOP-10_3x3mm_P0.5mm; LCSC C11355
U3: RP2040; RP2040-QFN-56; LCSC C2040
U4: XC6206P332MR-G; SOT-23; LCSC C5446
U6: LM66200; SOT-583-8; LCSC C3235556
VIK1: VIK Conn; LCSC C479750
Y1: 12MHz; Crystal_SMD_3225-4Pin_3.2x2.5mm; LCSC C9002

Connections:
+1V1: C4.1, C5.1, C6.1, U3.23 (DVDD), U3.45 (VREG_VOUT), U3.50 (DVDD)
+3V3: C1.1, C7.1, C8.1, C9.1, C10.1, C11.1, C12.1, C13.1, C14.1, C15.1, C17.2, C18.1, D1.4 (VDD), J3.2, Q1.1 (G), R2.1, R13.2, U1.8 (VCC), U2.1 (VCC), U3.1 (IOVDD), U3.10 (IOVDD), U3.22 (IOVDD), U3.33 (IOVDD), U3.42 (IOVDD), U3.43 (ADC_AVDD), U3.44 (VREG_VIN), U3.48 (USB_VDD), U3.49 (IOVDD), U4.2 (VO), U5.1 (VCC), VIK1.1
+5V: C16.2, J3.1, Q2.2 (S), Q3.2 (S), Q4.2 (S), R14.2, R16.1, U4.3 (VI), U6.2 (VOUT), U6.7 (VOUT), VIK1.6
/C1: FPC1.21, FPC2.3, J3.8, U3.37 (GPIO25)
/C2: FPC1.19, FPC2.4, J3.9, U3.36 (GPIO24)
/C3: FPC1.18, FPC2.5, J3.10, U3.35 (GPIO23)
/C4: FPC1.17, FPC2.6, J3.11, U3.34 (GPIO22)
/C5: FPC1.16, FPC2.7, J3.12, U3.32 (GPIO21)
/C6: FPC1.15, FPC2.8, J3.13, U3.31 (GPIO20)
/C7: FPC1.14, J5.11, U3.13 (GPIO10)
/CC1: J1.A5 (CC1), R3.1
/CC2: J1.B5 (CC2), R4.1
/CC2_1: J2.A5 (CC1), R10.1
/CC2_2: J2.B5 (CC2), R11.1
/D2_+: R8.1, U3.2 (GPIO0)
/D2_-: R9.1, U3.3 (GPIO1)
/D_+: R5.2, U3.47 (D+)
/D_-: R6.2, U3.46 (D-)
/GPIO28: J3.5, U3.40 (GPIO28/ADC2)
/GPIO29: J3.4, U3.41 (GPIO29/ADC3)
/LED_DATA: FPC1.20, J5.3, JP2.1 (A), Q1.3 (D), R14.1
/LED_INTERDATA: FPC1.7, FPC2.9
/R1: FPC1.13, J5.4, U3.5 (GPIO3)
/R2: FPC1.12, J5.5, U3.6 (GPIO4)
/R3: FPC1.11, J5.6, U3.7 (GPIO5)
/R4: FPC1.10, J5.7, U3.8 (GPIO6)
/R5: FPC1.9, J5.8, U3.9 (GPIO7)
/R6: FPC1.8, J5.9, U3.11 (GPIO8)
/R7: FPC2.1, J5.10, U3.12 (GPIO9)
/RGB: Q1.2 (S), U3.4 (GPIO2)
/VBUS1: J2.A4 (VBUS), J2.A9 (VBUS), J2.B4 (VBUS), J2.B9 (VBUS), Q4.3 (D), U6.3 (VIN1)
/VBUS2: J1.A4 (VBUS), J1.A9 (VBUS), J1.B4 (VBUS), J1.B9 (VBUS), Q3.3 (D), U6.6 (VIN2)
/XTAL_O: C3.2, R7.1, Y1.1
/drive: C18.2, Q3.1 (G), Q4.1 (G), R12.2
/sel: R15.2, U2.2 (SEL), U3.27 (GPIO16), U5.2 (SEL)
/~USB_BOOT: R1.1, SW1.2
CS: R1.2, U1.1 (~CS), U3.56 (QSPI_SS_N)
D2_N: R9.2, U2.8 (HSD2-), U5.6 (HSD1-)
D2_P: R8.2, U2.9 (HSD2+), U5.7 (HSD1+)
D2_USB_N: J2.A7 (D-), J2.B7 (D-), U5.4 (D-)
D2_USB_P: J2.A6 (D+), J2.B6 (D+), U5.3 (D+)
D_N: R6.1, U2.6 (HSD1-), U5.8 (HSD2-)
D_P: R5.1, U2.7 (HSD1+), U5.9 (HSD2+)
D_USB_N: J1.A7 (D-), J1.B7 (D-), U2.4 (D-)
D_USB_P: J1.A6 (D+), J1.B6 (D+), U2.3 (D+)
GND: C1.2, C2.1, C3.1, C4.2, C5.2, C6.2, C7.2, C8.2, C9.2, C10.2, C11.2, C12.2, C13.2, C14.2, C15.2, C16.1, C17.1, D1.2 (VSS), D2.1 (K), FPC1.3, FPC1.4, FPC1.5, FPC1.6, FPC2.2, J1.A1 (GND), J1.A12 (GND), J1.B1 (GND), J1.B12 (GND), J1.S1 (SHIELD), J2.A1 (GND), J2.A12 (GND), J2.B1 (GND), J2.B12 (GND), J2.S1 (SHIELD), J3.3, J5.2, R3.2, R4.2, R10.2, R11.2, R12.1, SW1.1, SW2.1, U1.4 (GND), U2.5 (GND), U2.10 (~OE), U3.19 (TESTEN), U3.57 (GND), U4.1 (GND), U5.5 (GND), U5.10 (~OE), U6.1 (GND), U6.4 (~ON), U6.5 (GND), VIK1.2, Y1.2, Y1.4
LED_ON: Q2.1 (G), U3.14 (GPIO11)
LED_PWR: FPC1.1, FPC1.2, FPC2.10, J5.1, Q2.3 (D)
NEOPIX: D1.3 (DIN), U3.28 (GPIO17)
unnamed: D2.2 (A), JP1.2 (B)
unnamed: JP1.1 (A), R16.2
unnamed: JP2.2 (B), VIK1.5
unnamed: R13.1, R15.1, U6.8 (ST)
QSPI_CLK: U1.6 (CLK), U3.52 (QSPI_SCLK)
SCL: U3.30 (GPIO19), VIK1.4
SD0: U1.5 (DI(IO0)), U3.53 (QSPI_SD0)
SD1: U1.2 (DO(IO1)), U3.55 (QSPI_SD1)
SD2: U1.3 (IO2), U3.54 (QSPI_SD2)
SD3: U1.7 (IO3), U3.51 (QSPI_SD3)
SDA: U3.29 (GPIO18), VIK1.3
SPI1_CS: U3.16 (GPIO13), VIK1.10
SPI1_RX: U3.15 (GPIO12), VIK1.11
SPI1_SCK: U3.17 (GPIO14), VIK1.12
SPI1_TX: U3.18 (GPIO15), VIK1.8
VIK_GP1: J3.7, U3.38 (GPIO26/ADC0), VIK1.7
VIK_GP2: J3.6, U3.39 (GPIO27/ADC1), VIK1.9
XTAL_IN: C2.2, U3.20 (XTAL_IN), Y1.3
XTAL_OUT: R7.2, U3.21 (XTAL_OUT)
~RESET: J3.14, R2.2, SW2.2, U3.26 (~RUN)

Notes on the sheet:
FPC Connectors
Program USB
RP2040 Processor
Secondary USB
Breakout Pins
Onboard LED
Power
Flash Memory
RGB LED 5V Logic/Power

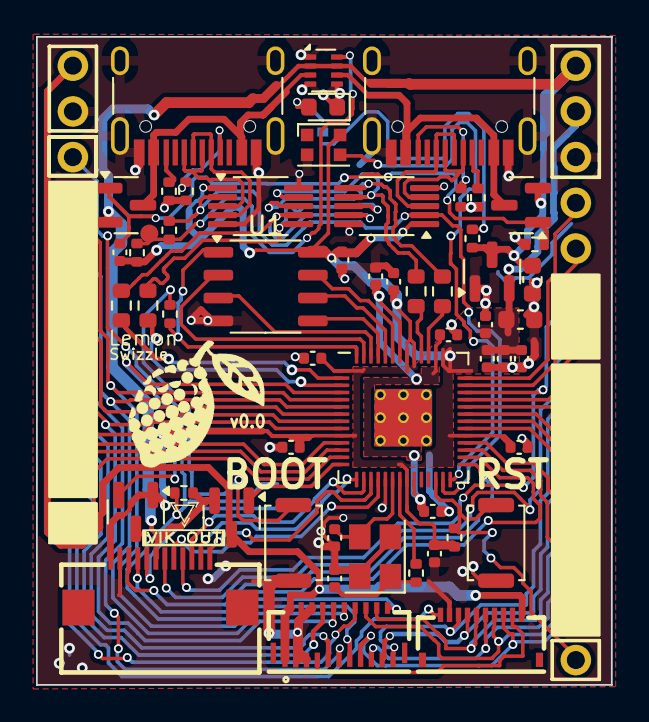
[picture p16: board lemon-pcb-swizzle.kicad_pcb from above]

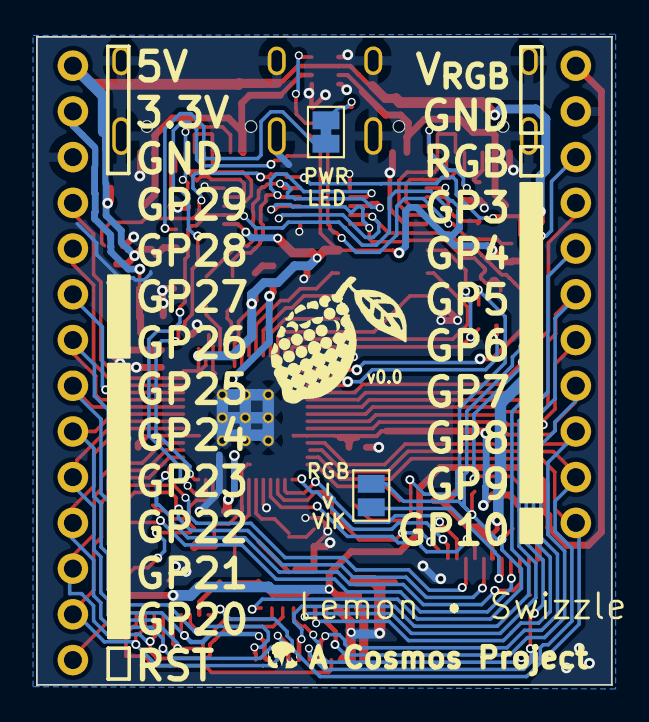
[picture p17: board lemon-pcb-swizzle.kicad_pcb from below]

Board: 2 copper layers, 31.9 x 36.0 mm, 59 parts (4 on the bottom side), 69 nets.

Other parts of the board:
svg2mod: G***; vik_small

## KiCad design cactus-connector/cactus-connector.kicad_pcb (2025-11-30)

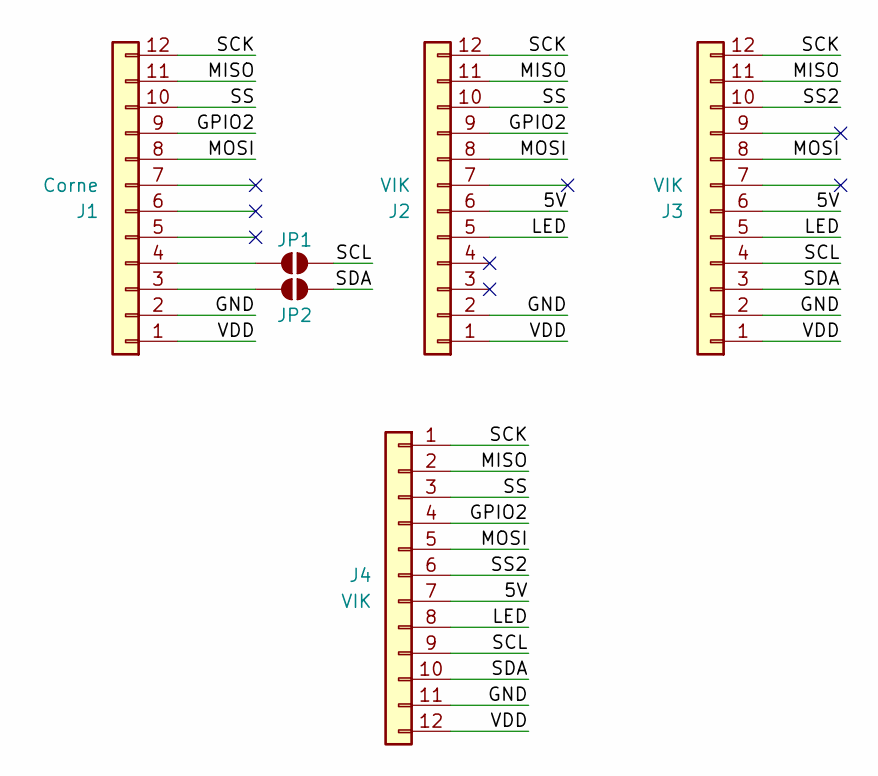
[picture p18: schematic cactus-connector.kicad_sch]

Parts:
J1: Corne; fpc
J2, J3, J4: VIK; fpc
JP1, JP2: SolderJumper_2_Open; SolderJumper-2_P1.3mm_Open_RoundedPad1.0x1.5mm

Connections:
/5V: J2.6, J3.6, J4.7
/GND: J1.2, J2.2, J3.2, J4.11
/GPIO2: J1.9, J2.9, J4.4
/LED: J2.5, J3.5, J4.8
/MISO: J1.11, J2.11, J3.11, J4.2
/MOSI: J1.8, J2.8, J3.8, J4.5
/SCK: J1.12, J2.12, J3.12, J4.1
/SCL: J3.4, J4.9, JP1.2 (B)
/SDA: J3.3, J4.10, JP2.2 (B)
/SS: J1.10, J2.10, J4.3
/SS2: J3.10, J4.6
/VDD: J1.1, J2.1, J3.1, J4.12
unnamed: J1.3, JP2.1 (A)
unnamed: J1.4, JP1.1 (A)

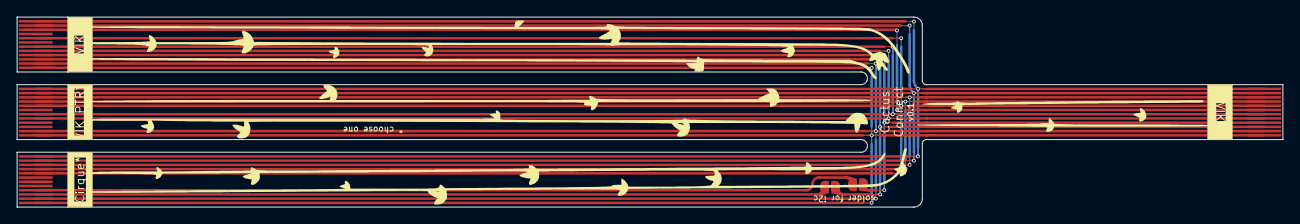
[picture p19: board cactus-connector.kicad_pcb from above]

Board: 2 copper layers, 149.9 x 22.5 mm, 6 parts (0 on the bottom side), 14 nets.

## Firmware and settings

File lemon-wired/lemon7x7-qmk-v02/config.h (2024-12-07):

/*
Copyright 2022 BentoBox Studio
This program is free software: you can redistribute it and/or modify
it under the terms of the GNU General Public License as published by
the Free Software Foundation, either version 2 of the License, or
(at your option) any later version.
This program is distributed in the hope that it will be useful,
but WITHOUT ANY WARRANTY; without even the implied warranty of
MERCHANTABILITY or FITNESS FOR A PARTICULAR PURPOSE.  See the
GNU General Public License for more details.
You should have received a copy of the GNU General Public License
along with this program.  If not, see http://www.gnu.org/licenses/.
*/

#pragma once

#define EE_HANDS

/* #define ROTATIONAL_TRANSFORM_ANGLE -30 */
/* #define POINTING_DEVICE_ROTATION_180_RIGHT */
/* #define POINTING_DEVICE_INVERT_X */

/* SPI & PMW3360 settings. */
#define SPI_DRIVER SPID1
#define SPI_SCK_PIN GP14
#define SPI_MISO_PIN GP12
#define SPI_MOSI_PIN GP15
#define POINTING_DEVICE_CS_PIN GP13

/* Reset. */
#define RP2040_BOOTLOADER_DOUBLE_TAP_RESET
/* #define RP2040_BOOTLOADER_DOUBLE_TAP_RESET_LED GP10 */

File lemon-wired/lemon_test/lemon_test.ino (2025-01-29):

// Based on Adafruit USB Host example
// LICENSE for that below -->

// /*********************************************************************
//  Adafruit invests time and resources providing this open source code,
//  please support Adafruit and open-source hardware by purchasing
//  products from Adafruit!

//  MIT license, check LICENSE for more information
//  Copyright (c) 2019 Ha Thach for Adafruit Industries
//  All text above, and the splash screen below must be included in
//  any redistribution
// *********************************************************************/

// USBHost is defined in usbh_helper.h
#include "usbh_helper.h"
#include <Adafruit_NeoPixel.h>
#include <hardware/pio.h>

// Language ID: English
#define LANGUAGE_ID 0x0409

typedef struct {
  tusb_desc_device_t desc_device;
  uint16_t manufacturer[32];
  uint16_t product[48];
  uint16_t serial[16];
  bool mounted;
} dev_info_t;

// CFG_TUH_DEVICE_MAX is defined by tusb_config header
dev_info_t dev_info[CFG_TUH_DEVICE_MAX] = { 0 };

class CustomNeoPixel : public Adafruit_NeoPixel {
public:
    // Custom constructor that overrides default behavior
    CustomNeoPixel(uint16_t n, int16_t p, neoPixelType t) { // Call the base class constructor
        begun = false;
        brightness = 0;
        pixels = NULL;
        endTime = 0;
        updateType(t);
        updateLength(n);
        setPin(p);
      #if defined(ARDUINO_ARCH_RP2040)
        // Find a free SM on one of the PIO's
        pio = pio1;
        sm = pio_claim_unused_sm(pio, false); // force PIO 1
        init = true;
      #endif
    }
};

// Which pin on the Arduino is connected to the NeoPixels?
// On a Trinket or Gemma we suggest changing this to 1:
#define LED_PIN    17
#define LED_EXT_PIN    2

// How many NeoPixels are attached to the Arduino?
#define LED_COUNT 1

// Declare our NeoPixel strip object:
CustomNeoPixel strip(LED_COUNT, LED_PIN, NEO_GRB + NEO_KHZ800);
// Argument 1 = Number of pixels in NeoPixel strip
// Argument 2 = Arduino pin number (most are valid)
// Argument 3 = Pixel type flags, add together as needed:
//   NEO_KHZ800  800 KHz bitstream (most NeoPixel products w/WS2812 LEDs)
//   NEO_KHZ400  400 KHz (classic 'v1' (not v2) FLORA pixels, WS2811 drivers)
//   NEO_GRB     Pixels are wired for GRB bitstream (most NeoPixel products)
//   NEO_RGB     Pixels are wired for RGB bitstream (v1 FLORA pixels, not v2)
//   NEO_RGBW    Pixels are wired for RGBW bitstream (NeoPixel RGBW products)

void setup() {
  Serial.begin(115200);

  pinMode(11, OUTPUT);
  digitalWrite(11, LOW);

  strip.begin();           // INITIALIZE NeoPixel strip object (REQUIRED)
  strip.show();            // Turn OFF all pixels ASAP
  strip.setBrightness(50); // Set BRIGHTNESS to about 1/5 (max = 255)

#if defined(CFG_TUH_MAX3421) && CFG_TUH_MAX3421
  // init host stack on controller (rhport) 1
  // For rp2040: this is called in core1's setup1()
  USBHost.begin(1);
#endif

//  while ( !Serial ) delay(10);   // wait for native usb
  Serial.println("TinyUSB Dual Device Info Example");
}

#if defined(CFG_TUH_MAX3421) && CFG_TUH_MAX3421
//--------------------------------------------------------------------+
// Using Host shield MAX3421E controller
//--------------------------------------------------------------------+
void loop() {
  USBHost.task();
  Serial.flush();
}

#elif defined(ARDUINO_ARCH_RP2040)
//--------------------------------------------------------------------+
// For RP2040 use both core0 for device stack, core1 for host stack
//--------------------------------------------------------------------+

//------------- Core0 -------------//
void loop() {
    rainbow(10);             // Flowing rainbow cycle along the whole strip
}

//------------- Core1 -------------//
void setup1() {
  //while ( !Serial ) delay(10);   // wait for native usb
  // configure pio-usb: defined in usbh_helper.h
  rp2040_configure_pio_usb();

  // run host stack on controller (rhport) 1
  // Note: For rp2040 pico-pio-usb, calling USBHost.begin() on core1 will have most of the
  // host bit-banging processing works done in core1 to free up core0 for other works
  USBHost.begin(1);
}

void loop1() {
  USBHost.task();
  Serial.flush();
}
#endif

//--------------------------------------------------------------------+
// TinyUSB Host callbacks
//--------------------------------------------------------------------+
void print_device_descriptor(tuh_xfer_t *xfer);

void utf16_to_utf8(uint16_t *temp_buf, size_t buf_len);

void print_lsusb(void) {
  bool no_device = true;
  for (uint8_t daddr = 1; daddr < CFG_TUH_DEVICE_MAX + 1; daddr++) {
    // TODO can use tuh_mounted(daddr), but tinyusb has an bug
    // use local connected flag instead
    dev_info_t *dev = &dev_info[daddr - 1];
    if (dev->mounted) {
      Serial.printf("Device %u: ID %04x:%04x %s %s\r\n", daddr,
                    dev->desc_device.idVendor, dev->desc_device.idProduct,
                    (char *) dev->manufacturer, (char *) dev->product);

      no_device = false;
    }
  }

  if (no_device) {
    Serial.println("No device connected (except hub)");
  }
}

// Invoked when device is mounted (configured)
void tuh_mount_cb(uint8_t daddr) {
  Serial.printf("Device attached, address = %d\r\n", daddr);

  dev_info_t *dev = &dev_info[daddr - 1];
  dev->mounted = true;

  // Get Device Descriptor
  tuh_descriptor_get_device(daddr, &dev->desc_device, 18, print_device_descriptor, 0);
}

/// Invoked when device is unmounted (bus reset/unplugged)
void tuh_umount_cb(uint8_t daddr) {
  Serial.printf("Device removed, address = %d\r\n", daddr);
  dev_info_t *dev = &dev_info[daddr - 1];
  dev->mounted = false;

  // print device summary
  print_lsusb();
}

void print_device_descriptor(tuh_xfer_t *xfer) {
  if (XFER_RESULT_SUCCESS != xfer->result) {
    Serial.printf("Failed to get device descriptor\r\n");
    return;
  }

  uint8_t const daddr = xfer->daddr;
  dev_info_t *dev = &dev_info[daddr - 1];
  tusb_desc_device_t *desc = &dev->desc_device;

  Serial.printf("Device %u: ID %04x:%04x\r\n", daddr, desc->idVendor, desc->idProduct);
  Serial.printf("Device Descriptor:\r\n");
  Serial.printf("  bLength             %u\r\n"     , desc->bLength);
  Serial.printf("  bDescriptorType     %u\r\n"     , desc->bDescriptorType);
  Serial.printf("  bcdUSB              %04x\r\n"   , desc->bcdUSB);
  Serial.printf("  bDeviceClass        %u\r\n"     , desc->bDeviceClass);
  Serial.printf("  bDeviceSubClass     %u\r\n"     , desc->bDeviceSubClass);
  Serial.printf("  bDeviceProtocol     %u\r\n"     , desc->bDeviceProtocol);
  Serial.printf("  bMaxPacketSize0     %u\r\n"     , desc->bMaxPacketSize0);
  Serial.printf("  idVendor            0x%04x\r\n" , desc->idVendor);
  Serial.printf("  idProduct           0x%04x\r\n" , desc->idProduct);
  Serial.printf("  bcdDevice           %04x\r\n"   , desc->bcdDevice);

  // Get String descriptor using Sync API
  Serial.printf("  iManufacturer       %u     ", desc->iManufacturer);
  if (XFER_RESULT_SUCCESS ==
      tuh_descriptor_get_manufacturer_string_sync(daddr, LANGUAGE_ID, dev->manufacturer, sizeof(dev->manufacturer))) {
    utf16_to_utf8(dev->manufacturer, sizeof(dev->manufacturer));
    Serial.printf((char *) dev->manufacturer);
  }
  Serial.printf("\r\n");

  Serial.printf("  iProduct            %u     ", desc->iProduct);
  if (XFER_RESULT_SUCCESS ==
      tuh_descriptor_get_product_string_sync(daddr, LANGUAGE_ID, dev->product, sizeof(dev->product))) {
    utf16_to_utf8(dev->product, sizeof(dev->product));
    Serial.printf((char *) dev->product);
  }
  Serial.printf("\r\n");

  Serial.printf("  iSerialNumber       %u     ", desc->iSerialNumber);
  if (XFER_RESULT_SUCCESS ==
      tuh_descriptor_get_serial_string_sync(daddr, LANGUAGE_ID, dev->serial, sizeof(dev->serial))) {
    utf16_to_utf8(dev->serial, sizeof(dev->serial));
    Serial.printf((char *) dev->serial);
  }
  Serial.printf("\r\n");

  Serial.printf("  bNumConfigurations  %u\r\n", desc->bNumConfigurations);

  // print device summary
  print_lsusb();
}

//--------------------------------------------------------------------+
// String Descriptor Helper
//--------------------------------------------------------------------+

static void _convert_utf16le_to_utf8(const uint16_t *utf16, size_t utf16_len, uint8_t *utf8, size_t utf8_len) {
  // TODO: Check for runover.
  (void) utf8_len;
  // Get the UTF-16 length out of the data itself.

  for (size_t i = 0; i < utf16_len; i++) {
    uint16_t chr = utf16[i];
    if (chr < 0x80) {
      *utf8++ = chr & 0xff;
    } else if (chr < 0x800) {
      *utf8++ = (uint8_t) (0xC0 | (chr >> 6 & 0x1F));
      *utf8++ = (uint8_t) (0x80 | (chr >> 0 & 0x3F));
    } else {
      // TODO: Verify surrogate.
      *utf8++ = (uint8_t) (0xE0 | (chr >> 12 & 0x0F));
      *utf8++ = (uint8_t) (0x80 | (chr >> 6 & 0x3F));
      *utf8++ = (uint8_t) (0x80 | (chr >> 0 & 0x3F));
    }
    // TODO: Handle UTF-16 code points that take two entries.
  }
}

// Count how many bytes a utf-16-le encoded string will take in utf-8.
static int _count_utf8_bytes(const uint16_t *buf, size_t len) {
  size_t total_bytes = 0;
  for (size_t i = 0; i < len; i++) {
    uint16_t chr = buf[i];
    if (chr < 0x80) {
      total_bytes += 1;
    } else if (chr < 0x800) {
      total_bytes += 2;
    } else {
      total_bytes += 3;
    }
    // TODO: Handle UTF-16 code points that take two entries.
  }
  return total_bytes;
}

void utf16_to_utf8(uint16_t *temp_buf, size_t buf_len) {
  size_t utf16_len = ((temp_buf[0] & 0xff) - 2) / sizeof(uint16_t);
  size_t utf8_len = _count_utf8_bytes(temp_buf + 1, utf16_len);

  _convert_utf16le_to_utf8(temp_buf + 1, utf16_len, (uint8_t *) temp_buf, buf_len);
  ((uint8_t *) temp_buf)[utf8_len] = '\0';
}

// Rainbow cycle along whole strip. Pass delay time (in ms) between frames.
void rainbow(int wait) {
  // Hue of first pixel runs 5 complete loops through the color wheel.
  // Color wheel has a range of 65536 but it's OK if we roll over, so
  // just count from 0 to 5*65536. Adding 256 to firstPixelHue each time
  // means we'll make 5*65536/256 = 1280 passes through this loop:
  for(long firstPixelHue = 0; firstPixelHue < 5*65536; firstPixelHue += 256) {
    // strip.rainbow() can take a single argument (first pixel hue) or
    // optionally a few extras: number of rainbow repetitions (default 1),
    // saturation and value (brightness) (both 0-255, similar to the
    // ColorHSV() function, default 255), and a true/false flag for whether
    // to apply gamma correction to provide 'truer' colors (default true).
    strip.rainbow(firstPixelHue);
    // Above line is equivalent to:
    // strip.rainbow(firstPixelHue, 1, 255, 255, true);
    strip.show(); // Update strip with new contents
    delay(wait);  // Pause for a moment
  }
}

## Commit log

2024-12-08 Add gerbers for Plum Twist
2025-02-20 Add microcontrollers, restructure README
    [lemon-pcb-wireless.kicad_pcb, lemon-pcb-wireless.kicad_sch, lemon-pcb.kicad_pcb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]
2025-02-20 Add wireless schematic pdf
2025-03-24 Update Wired Lemon V03 information
    [lemon-pcb.kicad_pcb, lemon-pcb.kicad_sch]
2025-03-27 Update wireless pinout
2025-06-24 Bring Plum Twist in repo up to date with store version
    [plum-twist.kicad_pcb]
2025-07-14 Update gerbers & remove extra silkscreen
    [plum-twist.kicad_pcb]
2025-07-25 Lemon wired V0.4, Lemon wireless V0.3
    [lemon-pcb-wireless.kicad_pcb, lemon-pcb-wireless.kicad_sch, lemon-pcb.kicad_pcb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]
2025-09-25 [Plum Twist] Add assembly instructions
    Fixes #1
2025-10-28 Add LED test UF2
2025-11-30 Add Cactus Connector
    [cactus-connector.kicad_pcb, cactus-connector.kicad_sch]
2026-03-13 Rename lemon-microcontroller folder
    [lemon-pcb.kicad_pcb, lemon-pcb.kicad_sch]
2026-03-13 Lemon wired swizzle
    [lemon-pcb-swizzle.kicad_pcb, lemon-pcb-swizzle.kicad_sch]
2026-04-27 Lemon Wireless v0.4
    [lemon-pcb-wireless.kicad_pcb, lemon-pcb-wireless.kicad_sch]
